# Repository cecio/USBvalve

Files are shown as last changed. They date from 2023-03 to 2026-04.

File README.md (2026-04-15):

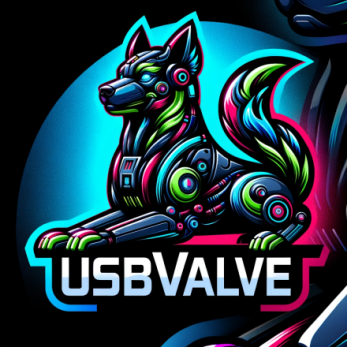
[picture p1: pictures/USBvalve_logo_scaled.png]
logo, landscape, dark text, transparent background
<h1></a></h1>

> [!NOTE]
> **USBvalve Version 1.0.0**
>
> A complete rewrite of the application has been done:
> - moved away from Arduino IDE environment, now the code is written for the [Pi Pico SDK](https://github.com/raspberrypi/pico-sdk)
> - dependencies on external libraries have been reduced a lot
> - USB host support for Low Speed devices is now more robust (ATTiny85, EvilCrow, etc)
> -  hardware and functionalities are almost unchanged, see the [notes](https://github.com/cecio/USBvalve#notes-about-bootsel-and-version--100) below for details 

### *Expose USB activity on the fly*

<p float="left">
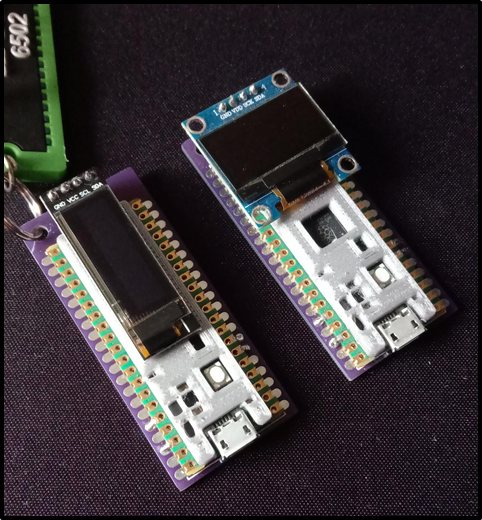
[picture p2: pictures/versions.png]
The two models

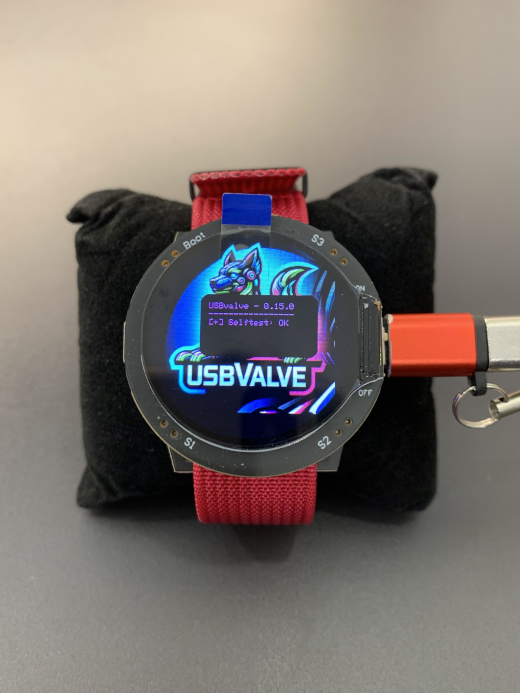
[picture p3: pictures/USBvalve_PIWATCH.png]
The Watch

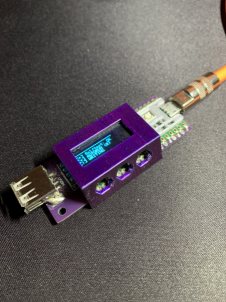
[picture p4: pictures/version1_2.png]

</p>

I'm sure that, like me, you were asked to put your USB drive in an *unknown* device...and then the doubt: 

what happened to my  poor dongle, behind the scene? Stealing my files? Encrypting them? Or  *just* installing a malware? With **USBvalve** you can spot this out in  seconds: built on super cheap off-the-shelf hardware you can quickly  test any USB file system activity and understand what is going on before it's too late!

With **USBvalve** you can have an immediate feedback about what happen to the drive; the screen will show you if the *fake* filesystem built on the device is accessed, read or written:

<p float="left">
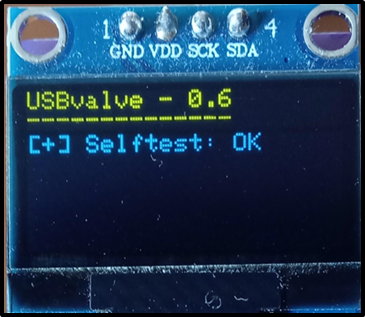
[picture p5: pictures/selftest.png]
Selftest

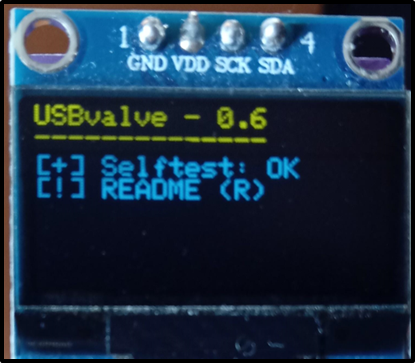
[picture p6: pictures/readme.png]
Readme

</p>

and from version `0.8.0` you can also use it as USB Host to detect *BADUSB* devices:

<p float="left">
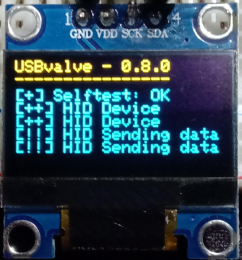
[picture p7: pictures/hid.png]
HID

</p>

This is an example of the *BADUSB* debugger available on serial port:

<p float="left">

</p>

If you prefer videos, you can also have a look to my [Insomni'hack Presentation](https://www.youtube.com/watch?v=jy1filtQY4w)

## USBvalve Watch

Starting from version `0.15.0` a new *Pi Pico Watch* version is supported. To compile the new version you have to uncomment the `#define PIWATCH` line at the beginning of the code. The hardware is a RP2040-based 1.28-inch TFT display and watch board. You can find some more info [here](https://www.raspberrypi.com/news/how-to-build-your-own-raspberry-pi-watch/).
This is also fully compatible with the [Waveshare RP2040-LCD-1.28](https://www.waveshare.com/wiki/RP2040-LCD-1.28).

## Repository Structure

`docs`: documentation about the project, with a presentation where you can have a look to all the features

`firmware`: pre-built firmwares for the Raspberry Pi Pico. You can just use these and flash them on the board. We have several different versions, for 32 or 64 lines OLEDs, for Pico 1 or Pico2, Pi Pico Watch, etc

`PCB`: Gerber file if you want to print the custom PCB . It's not mandatory, you can use your own or build it on a breadboard

`src` and `data`: sources, if you want to modify and build the firmware yourself

`utils`: some utilities you may use to build a custom FS

`pictures`: images and resources used in this doc

`STL`: STL files for enclosure. In `1.1` and `1.2` folders there are full enclosures (thanks to [WhistleMaster](https://github.com/WhistleMaster)). In folders `1.2_64` and `1.2_64_simple` there are enclosures for the 128x64 screen (thanks to [rtmq0227](https://github.com/rtmq0227)). If you want something lighter to protect the LCD you can go with `USBvalve_sliding_cover.stl`.

## Build USBvalve

### Part list

If you want to build your own, you need:

- A Raspberry Pi Pico 1 or 2 (or another RP2040 based board)
- an I2C OLED screen 128x64 or 128x32 (**SSD1306**)
- (optional) a **USBvalve** PCB or a breadboard
- (optional) a 3D printed spacer to isolate the screen from the board (https://www.thingiverse.com/thing:4748043), but you can use a piece of electrical tape instead

### Notes about BOOTSEL and version >= 1.0.0

In the `0.x.x` versions, BOOTSEL was used to reset the device or print the number of HID events (press > 2s).
The polling of BOOTSEL was creating some issues to the *BADUSB* detection so this was removed from version `1.0.0` and replaced with the following two options:
- solder a button between `GP0` and `GND` (pads 1 and 3, see pic below to see an example) to have the same functions
- use the commands `r` (reset) and `h` (HID events) from the serial monitor

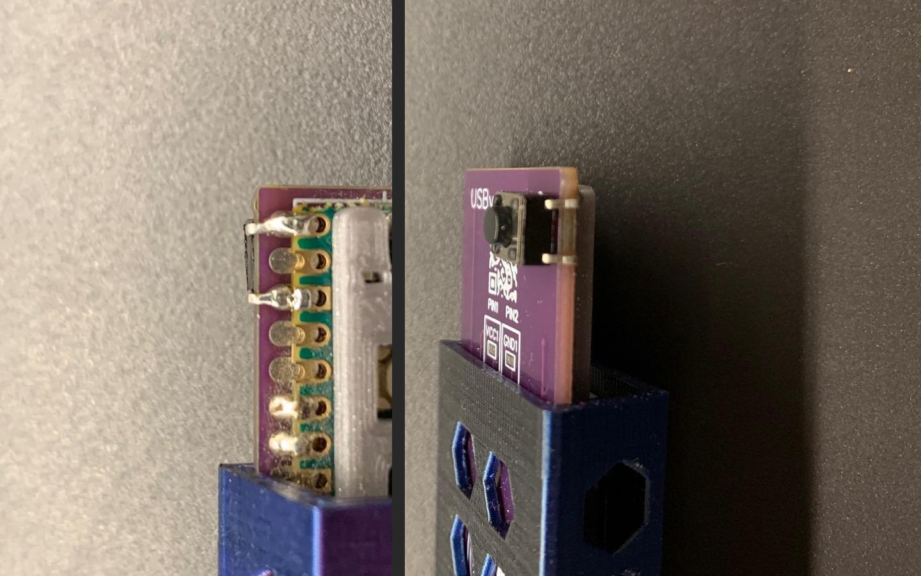
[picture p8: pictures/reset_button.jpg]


In `PCB` you'll find also a version `1.3` of the board, with some holes on pads 1 and 3 to facilitate the mount of the button. But as you can see, you can also use your old version.

If you are not using the *BADUSB* functions or if you prefer to have less coverage on detection but keep BOOTSEL usage, I'm also providing a firmware created with *bootsel* enabled (see folder and releases).

### Building instructions

> Thanks to [Tz1rf](https://github.com/Tz1rf) we also have two great videos: one explaining the [building](https://youtu.be/7ymk8hD7-Hc) process step-by-step, and another showing how to [upload firmware](https://youtu.be/Tp8xvrlqxUY) and use the tool.

Almost all the job is done directly on the board by the software, so you just need to arrange the connection with the OLED for output.

Starting from version 0.8.0 of the firmware, **USBvalve** can detect HID devices (used to detect *BADUSB*). This require an additional USB port behaving as Host. If you are not interested in this, you can use the old instructions [in docs folder](https://github.com/cecio/USBvalve/blob/main/docs/BUILDING-1.1.md) and use PCB version `1.1`. Otherwise go ahead with PCB version `1.2` (we have version for USB-A or USB-B, see folder).

#### With USBvalve PCB

<p float="left">
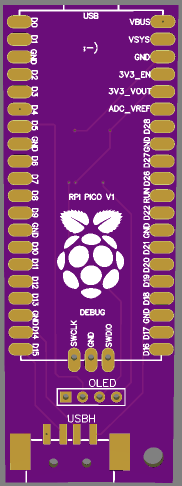
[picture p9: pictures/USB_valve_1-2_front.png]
  
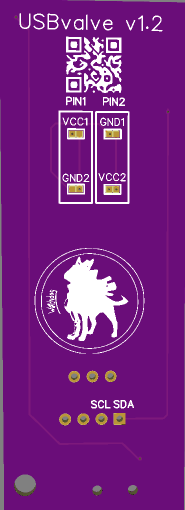
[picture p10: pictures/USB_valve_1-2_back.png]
   
</p>

- solder a USB female port in `USBH` area. This is for version `A`, but there is a version for USB `Micro-B` as well if you prefer
- place the Raspberry Pi Pico on the silk screen on the front 
- you don't need to solder all the PINs. Just the following:
  - D4 and D5 (left side)
  - D14 and D15 (left side)
  - GND (right side, third pin from the top)
  - GND (right side, third pin from the bottom)
  - 3v3_OUT (right side)
  - VBUS (right side)
  - the 3 DEBUG pin on the bottom: SWCLK, GND and SWDIO
- place the 3D printer spacer or a piece of tape on the parts of the OLED that my touch the Raspberry
- solder the OLED (with a header) on the 4 PIN space

Some of the OLEDs have the GND and VCC PINs swapped, so I built the PCB to be compatible with both versions: 

For example if your OLED has GND on PIN1 and VCC on PIN2 like this:

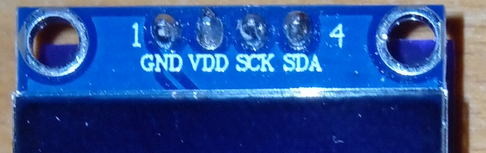
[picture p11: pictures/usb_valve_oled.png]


You have to place a blob of solder on these two pads on the back of the PCB:

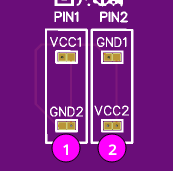
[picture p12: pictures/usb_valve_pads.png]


Otherwise you should the opposite and place the solder on the other PADs:

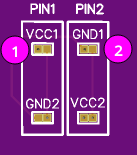
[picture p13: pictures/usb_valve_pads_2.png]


#### Without USBvalve PCB

Pico Pi

If you are using a breadboard or just wiring, all you have to do is to ensure to connect the proper PINs at the OLED screen and to the Host USB port.

The mapping is the following:

- PIN6 of Pi --> OLED SDA
- PIN7 of Pi --> OLED SCL 
- PIN19 of Pi --> D+ of USB Host
- PIN20 of Pi --> D- of USB Host
- PIN23 (GND) of Pi --> GND of USB Host
- PIN38 (GND) of Pi --> OLED GND
- PIN36 (3V3OUT) of Pi --> OLED VCC
- PIN40 (VBUS) of Pi --> VCC of USB Host

If you want to use the DEBUG functions, you can also place a header on the 3 SWD PINs at the bottom of the board.

#### With USBpipe PCB

> [!CAUTION]
> This PCB is for experienced electronic makers
> **DON'T USE IT IF YOU AREN'T SURE YOU CAN HANDLE IT!**

> [!NOTE]
> R7 and R8 aren't actually connected to anything. They are added for circuit debugging purposes.
> So they don't show up in the BOM

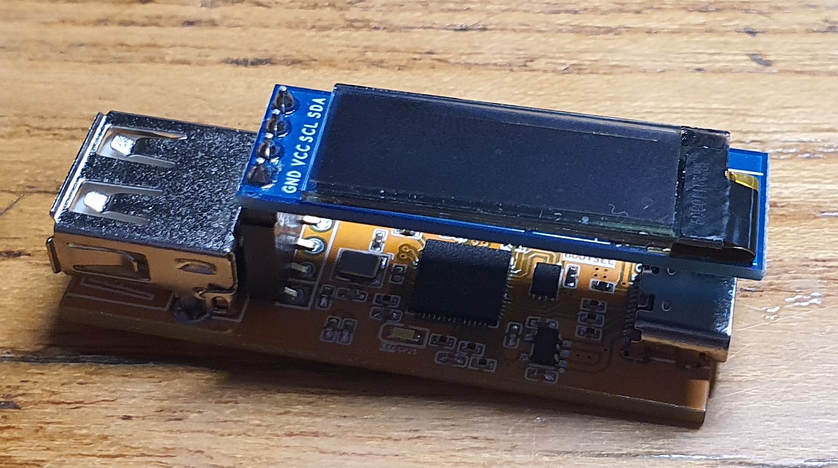
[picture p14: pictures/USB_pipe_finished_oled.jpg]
USBpipe PCB


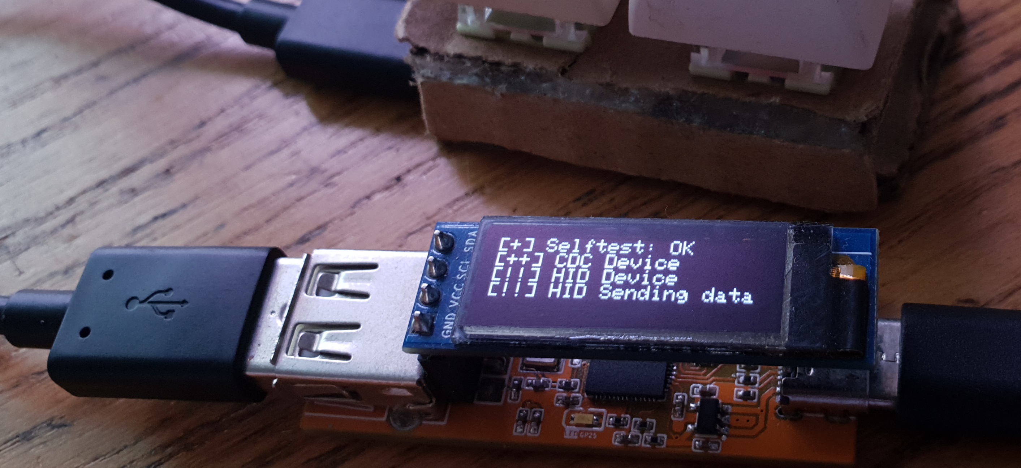
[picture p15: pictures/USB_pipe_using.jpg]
USBpipe


[USBpipe](https://github.com/LiPolymer/smartUSBPipe) is a dedicated PCB for this project.

You can find everything you need in `./PCB/USBpipe/` folder.

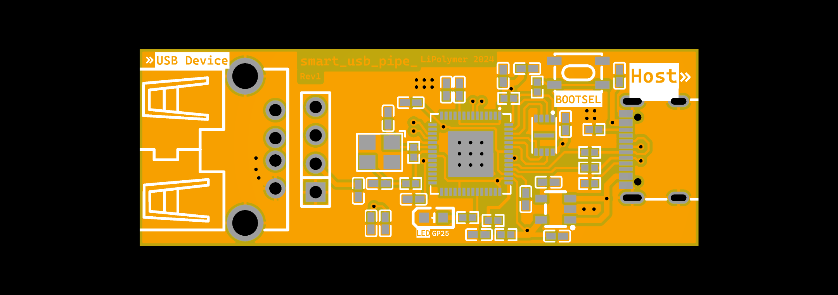
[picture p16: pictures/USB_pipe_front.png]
Front


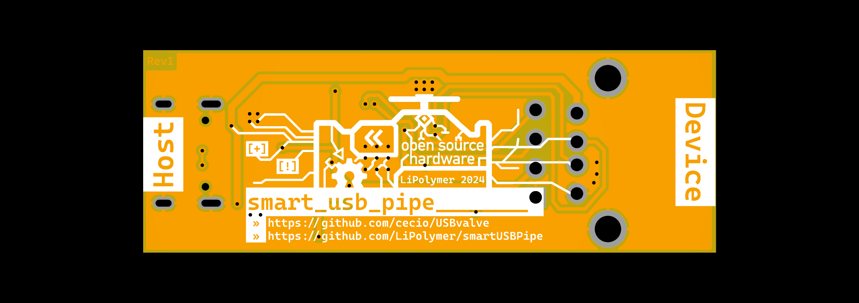
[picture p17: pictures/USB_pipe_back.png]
Back


### Flash Firmware

To flash the firmware, follow these steps:

- Connect the Raspberry Pi Pico with the USB cable, by keeping the *BOOTSEL* button pressed (the big white button on the board)
- release the button
- you will see a new drive on the system, named `RPI-RP2` (in Linux envs you may have to manually mount it)
- copy the proper firmware file (with extension `uf2`) in the folder, depending on the OLED you used
- wait few seconds until the mounted folder disappear

It's done!

### Anti-Detection

I don't know if it will ever be the case, but you may want to customize the firmware in order to avoid detection done by *USBvalve-aware* malware :-)

I grouped most of the variables you may want to modify in this section of `usb_config.h` ([see Dockerfile below for rebuilding](https://github.com/cecio/USBvalve#dockerfile))

```C
// USB anti-detection settings
//
// Set USB IDs strings and numbers, to avoid possible detections.
// Remember that you can cusotmize FAKE_DISK_BLOCK_NUM as well
// for the same reason. Also DISK_LABEL in ramdisk.h can be changed.
//
// You can see here for inspiration: https://the-sz.com/products/usbid/
//
// Example:
//             0x0951 0x16D5    VENDORID_STR: Kingston   PRODUCTID_STR: DataTraveler
//
#define USB_VENDORID       0x0951
#define USB_PRODUCTID      0x16D5
#define USB_DESCRIPTOR     "DataTraveler"
#define USB_MANUF          "Kingston"
#define USB_SERIAL         "123456789A"
#define USB_VENDORID_STR   "Kingston"        // Up to 8 chars
#define USB_PRODUCTID_STR  "DataTraveler"    // Up to 16 chars
#define USB_VERSION_STR    "1.0"             // Up to 4 chars
```

### Building your firmware

Obviously you can also build your own firmware. To build you need the *Raspberry Pi Pico SDK* and this repoository.

Basic recompile instructions:
```
export PICO_SDK_PATH=</path/to/pico-sdk>

git clone --recursive https://github.com/cecio/USBvalve.git
cd USBvalve
mkdir build && cd build
cmake -DPICO_BOARD=pico ..   # or pico2 for standard build
make -j$(nproc)
# Output: build/src/USBvalve.uf2
```

If you want to re-create a new fake filesystem, you may want to have a look to the `utils` folder, where I placed some utilities to build a new one.

#### Dockerfile

If you want to build your own firmware, after you customized it, I provide a `Dockerfile` which builds a complete building environment and compile the firmware. 

Enter the following commands in the main `USBvalve` folder to build:

```
# To Build:
#       docker build -t usbvalve-sdk -f Dockerfile.sdk .
#
# To Run (default: pico, SSD1306 OLED 128x32):
#       docker run --rm -v $PWD:/mnt usbvalve-sdk
#
# Options (via environment variables):
#       BOARD=pico|pico2          Board target (default: pico)
#       OLED_HEIGHT=32|64         OLED display height (default: 32)
#       PIWATCH=1                 Use GC9A01 round TFT instead of SSD1306
#       USE_BOOTSEL=1             Enable BOOTSEL button (disrupts Low Speed USB)
#
# Examples:
#       docker run --rm -e BOARD=pico2 -v $PWD:/mnt usbvalve-sdk
#       docker run --rm -e PIWATCH=1 -v $PWD:/mnt usbvalve-sdk
#       docker run --rm -e BOARD=pico2 -e OLED_HEIGHT=64 -v $PWD:/mnt usbvalve-sdk
```

The firmware will be placed with extension `uf2` in folder `USBvalve_out`.

### Contribute

If you have ideas or improvements in your mind, I encourage you to open an issue so that we can improve the project together! Thanks!

### Support

If you have question or need support you can open an `Issue` here or reach me out on Twitter/X [@red5heep](https://twitter.com/red5heep)

### Community versions

The Community created some forks implementing support for other boards, or other modifications. **Thank you to everyone** who contributed to the development of **USBvalve**.
Here below an unofficial/incomplete/unsupported list:
- [USBvalve-tbfa-Mod](https://github.com/TryBreakFixAgain/USBvalve-tbfa-Mod)

## SAFETY WARNING

> [!WARNING]
> I've received a lot of questions about **USBvalve** and *USB killer devices*. **USBvalve** is not built to test these devices, it has not any kind of insulation or protection, so if you have the suspect you are dealing with one of these devices, test it with something else, NOT with **USBvalve** or you may damage the device, yourself or objects near to you.

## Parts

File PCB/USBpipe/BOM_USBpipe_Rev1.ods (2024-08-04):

No. | Quantity | Manufacturer Part | Value | Designato | Footprint | Comment | Manufacturer
1 | 1 | HX TS3425PA 250gf |  | BOOTSEL1 | SW-SMD_4P-L4.2-W3.4-P2.15-LS5.2 | HX TS3425PA 250gf | hanxia(韩下)
2 | 2 |  | 15pF | C1,C2 | C0402 | 15pF
3 | 3 |  | 2.2uF | C3,C4,C5 | C0402 | 2.2uF
4 | 8 |  | 100nF | C6,C7,C8,C9,C10,C11,C12,C13 | C0402 | 100nF
5 | 1 |  | 10nF | C14 | C0402 | 10nF
6 | 2 |  | 1uF | C15,C17 | C0402 | 1uF
7 | 1 |  | 10uF | C16 | C0402 | 10uF
8 | 1 | PZ254V-11-04P |  | H1 | HDR-TH_4P-P2.54-V-M | PZ254V-11-04P | XFCN(兴飞)
9 | 1 | SZYY0603B |  | LED1 | LED0603-R-RD_BLUE | SZYY0603B | yongyu(永裕光电)
10 | 1 |  | 10K | R1 | R0402 | 10K
11 | 2 |  | 5.1K | R2,R3 | R0402 | 5.1K
12 | 2 |  | 27R | R4,R5 | R0402 | 27R
13 | 1 |  | 200R | R6 | R0402 | 200R
14 | 1 |  | 1K | R9 | R0402 | 1K
15 | 1 |  | 1R | R10 | R0402 | 1R
16 | 1 |  | 470R | R11 | R0402 | 470R
17 | 1 | RP2040 |  | U1 | QFN-56_L7.0-W7.0-P0.40-TL-EP4.0 | RP2040 | Raspberry Pi(树莓派)
18 | 1 | W25Q16JVUXIQ |  | U2 | USON-8_L3.0-W2.0-P0.50-BL-EP | W25Q16JVUXIQ | WINBOND(华邦)
19 | 1 | Type-C-TOP_1 |  | U3 | USB-C-SMD_TYPE-C16PIN | Type-C-TOP_1
20 | 1 | SGM2028-3.3 |  | U4 | SOT-23-5_L3.0-W1.7-P0.95-LS2.8-BR | SGM2028-3.3 | SGMICRO(圣邦微)
21 | 1 | AF 90° WJDG |  | USB1 | USB-A-TH_AF-WJDG | AF 90° WJDG | SHOU HAN(首韩)
22 | 1 | X322512MSB4SI | 12MHz | X1 | OSC-SMD_4P-L3.2-W2.5-BL | 12MHz | YXC(扬兴晶振)
 | NOTE: R7 and R8 aren't actually connected to anything. They are added for circuit debugging purposes.
 | 注意: R7和R8为测试用焊盘,并不连接到任何元件

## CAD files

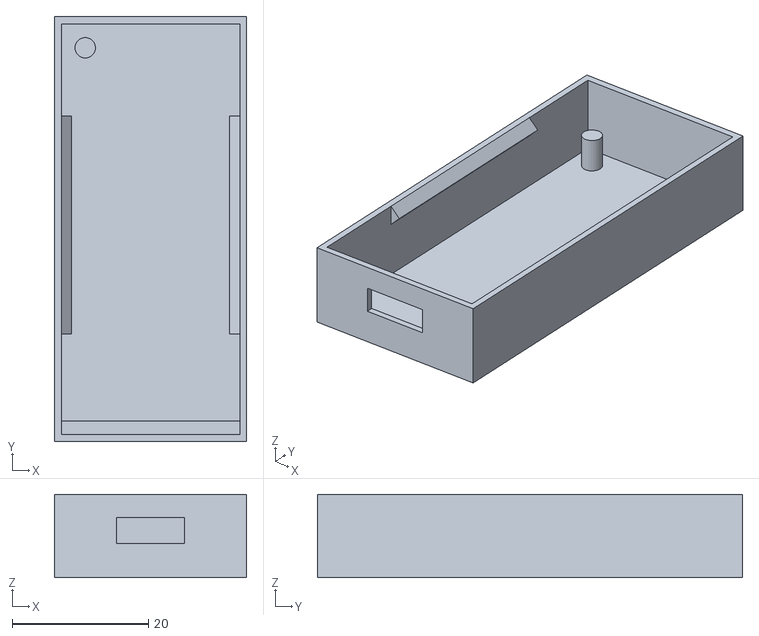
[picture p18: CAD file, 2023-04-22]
STL/1.1/Box_USBvalve_1.1.stl
28.2 x 62.4 x 12.2

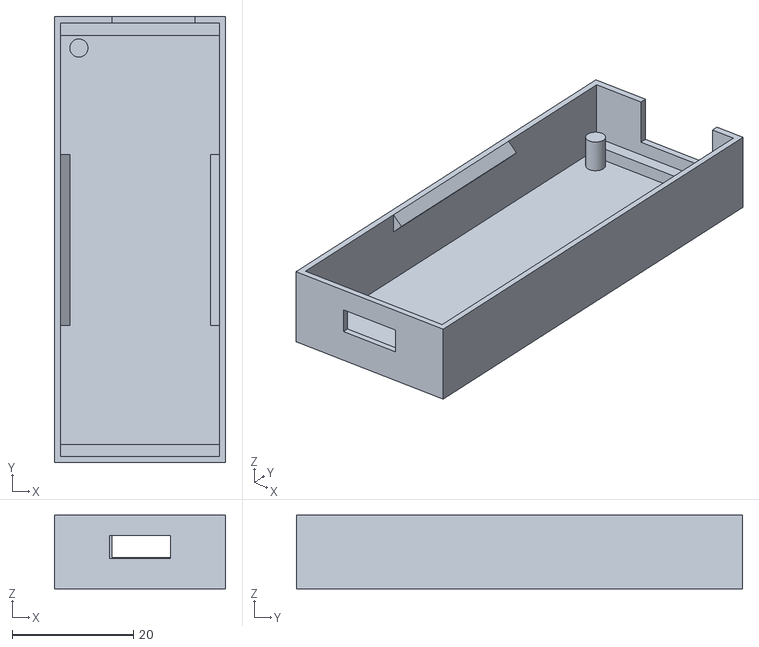
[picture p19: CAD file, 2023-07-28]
STL/1.2/Box_USBvalve_1.2.stl
28.2 x 73.5 x 12.2

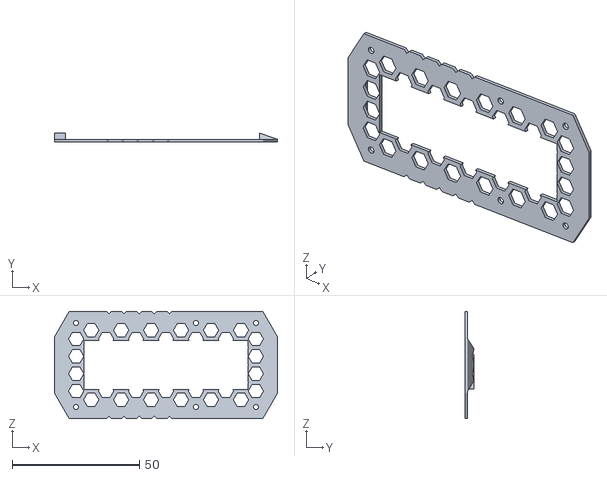
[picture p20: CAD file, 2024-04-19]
STL/1.2_64/renclosure_spacer.stl
87.5 x 3.50 x 42.1

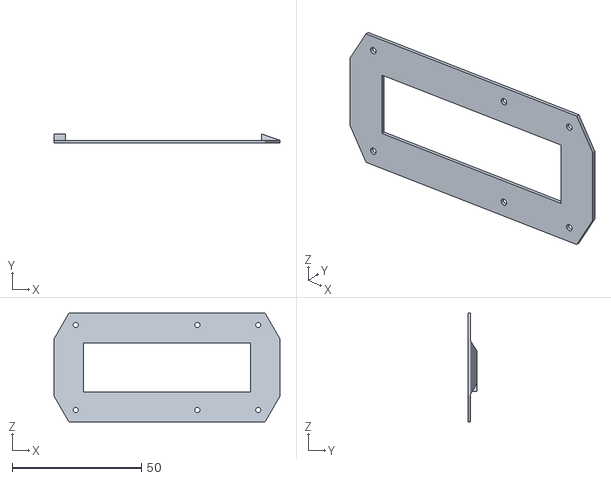
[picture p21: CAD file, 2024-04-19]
STL/1.2_64_simple/SimpleEnclosurex64_spacer.stl
87.5 x 3.50 x 42.1

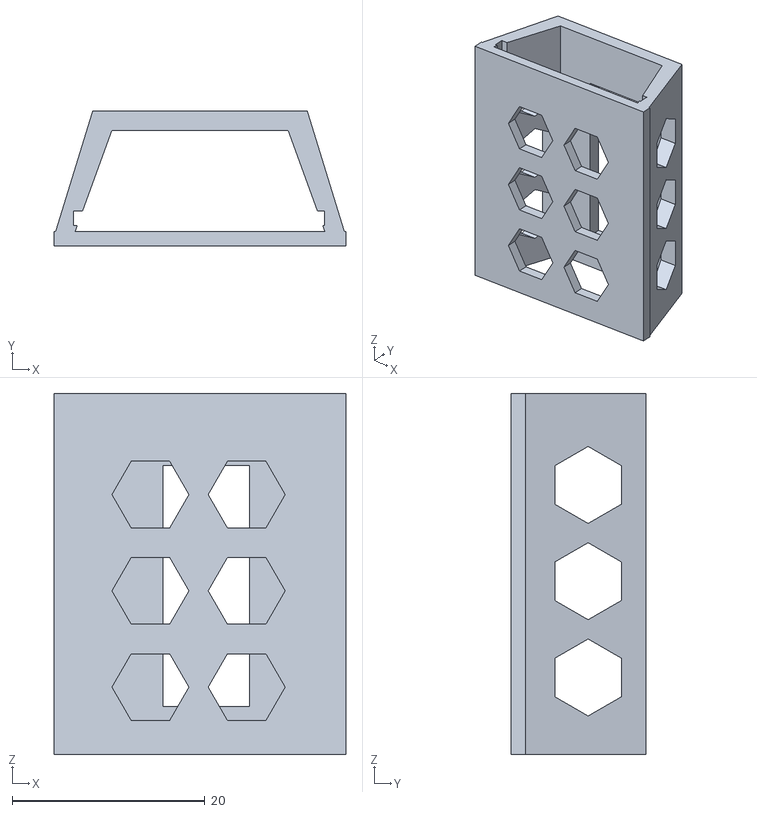
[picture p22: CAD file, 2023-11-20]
STL/USBvalve_sliding_cover.stl
30.3 x 14.0 x 37.5

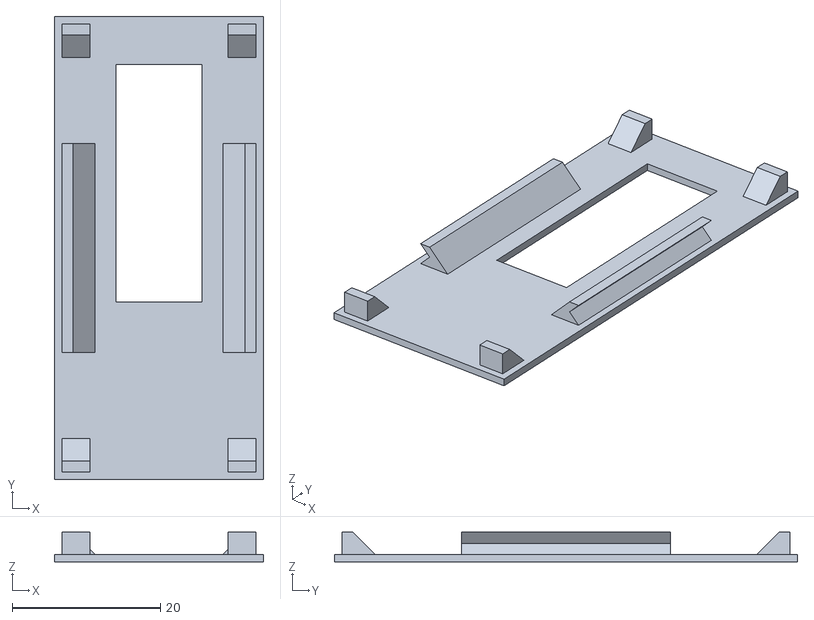
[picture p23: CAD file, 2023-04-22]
STL/1.1/Cover_32_USBvalve_1.1.stl
28.2 x 62.4 x 4.00

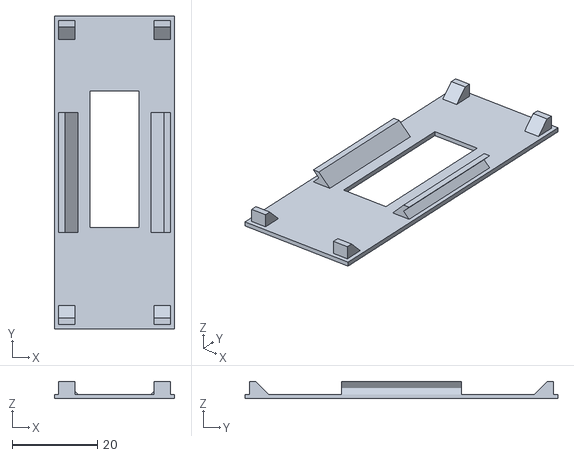
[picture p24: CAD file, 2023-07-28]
STL/1.2/Cover_32_USBvalve_1.2.stl
28.2 x 73.5 x 4.00

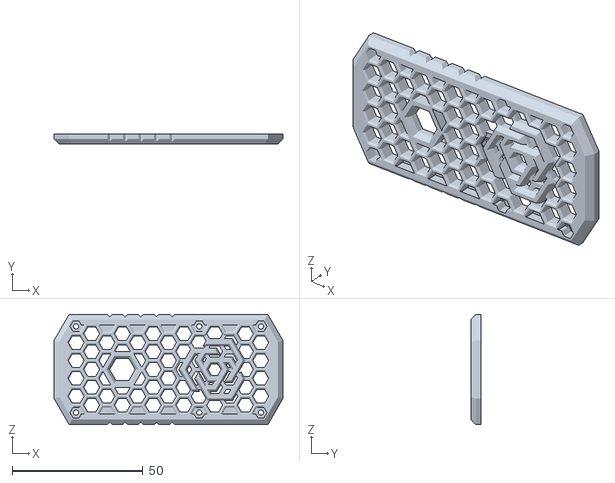
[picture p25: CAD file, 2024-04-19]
STL/1.2_64/renclosure_backplate.stl
87.5 x 4.00 x 42.1

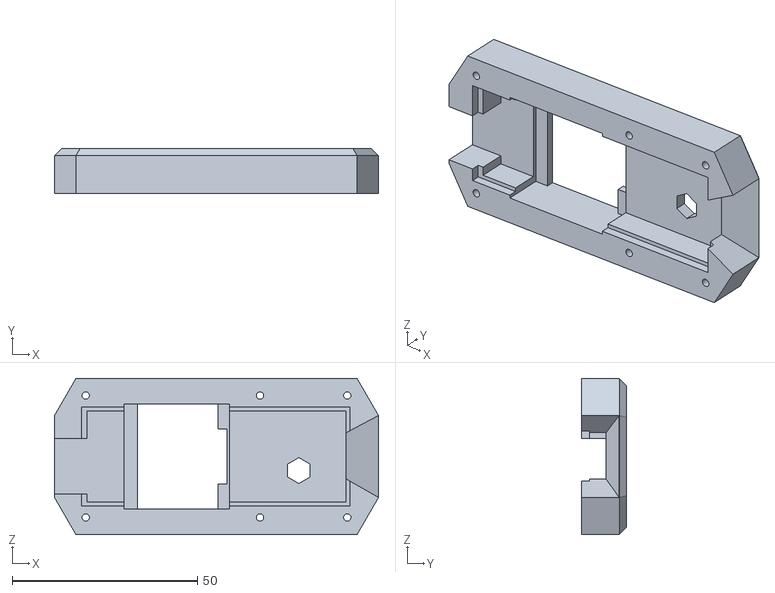
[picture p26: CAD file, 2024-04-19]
STL/1.2_64_simple/SimpleEnclosurex64.stl
87.5 x 12.2 x 42.1

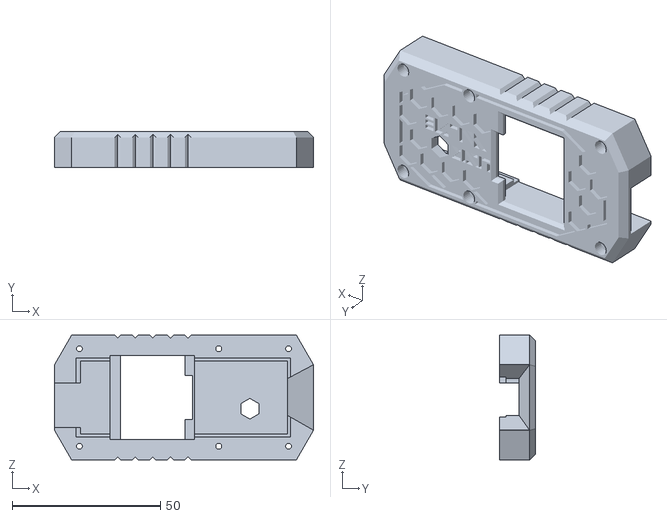
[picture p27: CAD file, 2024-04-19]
STL/1.2_64/renclosure.stl
87.5 x 12.2 x 42.1

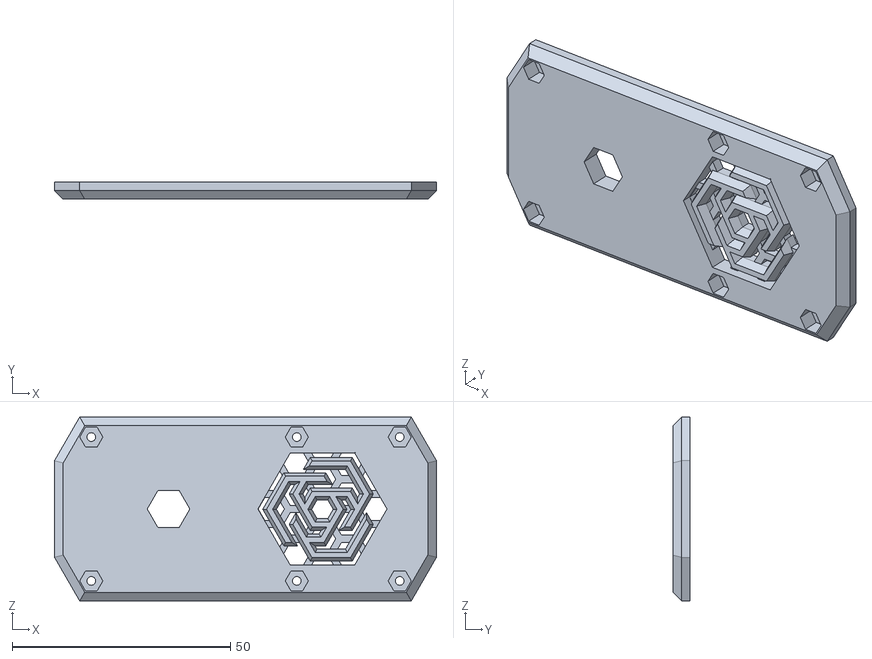
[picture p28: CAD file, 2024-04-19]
STL/1.2_64_simple/SimpleEnclosurex64_backplate.stl
87.5 x 4.00 x 42.1

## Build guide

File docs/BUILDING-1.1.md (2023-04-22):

#### With USBvalve PCB

<p float="left">
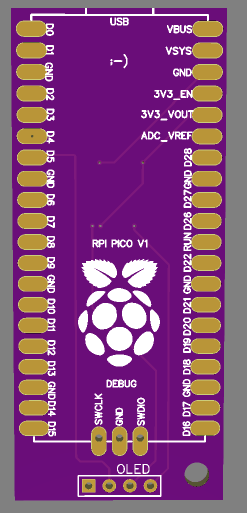
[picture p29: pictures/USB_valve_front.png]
  
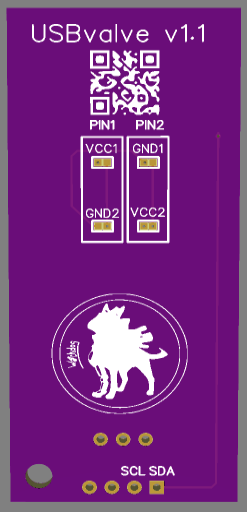
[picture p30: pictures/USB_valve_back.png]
   
</p>

- place the Raspberry Pi Pico on the silk screen on the front 
- you don't need to solder all the PINs. Just the following:
  - D4 and D5 (left side)
  - GND (right side)
  - 3v3_OUT (right side)
  - the 3 DEBUG pin on the bottom: SWCLK, GND and SWDIO
- place the 3D printer spacer or a piece of tape on the parts of the OLED that my touch the Raspberry
- solder the OLED (with a header) on the 4 PIN space

Some of the OLEDs have the GND and VCC PINs swapped, so I built the PCB to be compatible with both versions: 

For example if your OLED has GND on PIN1 and VCC on PIN2 like this:



You have to place a blob of solder on these two pads on the back of the PCB:



Otherwise you should the opposite and place the solder on the other PADs:



#### Without USBvalve PCB

Pico Pi

If you are using a breadboard or just wiring, all you have to do is to ensure to connect the proper PINs at the OLED screen.

The mapping is the following:

- PIN6 of Pi --> OLED SDA
- PIN7 of Pi --> OLED SCL 
- PIN38 (GND) of Pi --> OLED GND
- PIN36 (3V3OUT) of Pi --> OLED VCC

If you want to use the DEBUG functions, you can also place a header on the 3 SWD PINs at the bottom of the board.

### Flash Firmware

To flash the firmware, follow these steps:

- Connect the Raspberry Pi Pico with the USB cable, by keeping the *BOOTSEL* button pressed (the big white button on the board)
- release the button
- you will see a new drive on the system, named `RPI-RP2` (in Linux envs you may have to manually mount it)
- copy the proper firmware file (with extension `uf2`) in the folder, depending on the OLED you used
- wait few seconds until the mounted folder disappear

It's done!

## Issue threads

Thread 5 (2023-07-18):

KillerUSB

cecio, 2023-07-18:
Chances are that it will be destroyed, so we can think it as a **sacrificial device** ;-)
...it costs a few bucks :-)

Better this than your main PC!

**Need to be tested!**

csdragon83, 2023-08-28:
I also guess that it will be fried...

For USB-Kill I recommend:
https://usbkill.com/collections/usbkill-accessories/products/usbkill-shield
(even when the old one was cooler... you were able to do sparks with it)

cecio, 2023-08-28:
ah, I didn't know it existed! Nice!

Zorakie, 2024-03-22:
Hi, this my question is somewhat related.

If I add the USB-A for passthrough testing, and for some reason, that device will also sends power (like battery operated device, or something that is also plugged to the wall, say, USB-hub that also has power passthrough and is connected to laptop charger), is there any on-board protection for this power coming from the other side, or it will just fry the device?

Thanks! :)

cecio, 2024-03-22:
Usually host devices (even if battery operated) do not send power over the USB connection, they get power from it.
During my tests I used a lot of them and I never found one sending power over that line.
This does not exclude that a malfunctioning one (or a malicious one) can do it.

Looking at the Raspberry Pi Docs, I understand that the VBUS pin (the one attached to the power of the USB Host port) does not have a diode, so power coming in MAY damage the device (probably this depends on a lot of factors). A possible solution could be to attach the line to the VSYS pin, which actually have a diode. But in this case you may open an opposite issue: VBUS gets power from the USB Pico port, so it will be for sure at 5v and it will not damage your host. VSYS deliver the external power voltage (if you are powering the Pico externally) and that could damage your USB Host device (but only if you are powering it externally).

Side note: I see that you are referring to the USB-A as "passthrough" port, but it is not really that: the two USB ports are independent.

cecio, 2024-03-22:
Giving a deeper look at the Pico schematics, may be that even VSYS is not a solution in this case: if I'm not wrong the diode protects from backfeeding into the USB power source.
The real solution here is to apply an external diode probably.

frankrpeters, 2024-05-14:
As I also mentioned in the ATTiny/USBKill issue, a few TVS diodes and a polyfuse might protect the device and connected PC from damage.

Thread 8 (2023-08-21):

2 devices not recognized

csdragon83, 2023-08-21:
Hi!

First of all: you did a great job creating this little device...
I meanwhile made 3 if them...

But 2 hacking devices from me were not recognized...

1.:
"Duckhunter" is not recognized...

Duckhunter is a app within Nethunter that interprets Duckyscripts.
Nethunter is a Kali Linux arsenal that can be installed to Android devices..

In Nethunter there is the function "USB arsenal". With it you can enable the function "HID".
When I now start an attack at a computer the app "Duckhunter" interprets the Duckyscripts and types them in via the connected USB cable.
For that the android setting "USB Debugging" needs to be activated on the Android device.

Now I thought that the USB valve would also recognize the key strokes...
But it completely doesn't...
It doesn't recognize when I change my phone to HID mode and it doesn't recognize the key strokes...

2.:
The second device is a little "CJMCU" - a little Mini Atmega32U4 development board for about 7€ that also can do keystrokes...
At the moment I have set it to type in 0000 to 9999 but the USB valve also doesn't recognize the keystrokes of this little device...

Maybe you could add a function so that this devices also  can be recognized...

Best regards
Csdragon

cecio, 2023-08-21:
Thanks for the kind words, and for opening the issue.

A couple of questions:

- are the devices not recognized at all, or just the keystrokes? I mean, when you plug the device, do you see an `HID Device` message on the OLED screen, or nothing at all?
- for the NetHunter app, did you tried to switch before to HID and then (after that) plug the device into USBvalve?
- the CJMCU device is also named "CJMCU-Beetle"? I can try to buy one to do a couple of tests

Thanks,

cecio, 2023-08-21:
Ok, I think I found something, not sure if this is the same issue you are experiencing, but may be:

it looks like the overclocking of the CPU is in some way decreasing the compatibility with some HID devices, not sure why. May I send you a debug version of the firmware with a 120Mhz firmware (let me know if 32 o 64 lines screen) and may be you can do some testing with your devices?

Thanks,

csdragon83, 2023-08-22:
> it looks like the overclocking of the CPU is in some way decreasing the compatibility with some HID devices, not sure why. May I send you a debug version of the firmware with a 120Mhz firmware (let me know if 32 o 64 lines screen) and may be you can do some testing with your devices?

Would be no problem!
I've got a 32 lines display.

csdragon83, 2023-08-22:
To the CJMCU device: I hope I can manage to have a look at it this evening.

cecio, 2023-08-22:
No worries at all, take your time. And thanks for your help!

In the meantime, here is the link for a new test version (0.13.0): https://icedrive.net/s/8SbF9bD7N27k1vGYBtDVya9FCjzk

Let me know how it works with the two devices.

Thanks again.

csdragon83, 2023-08-28:
Hi!

Installed it to my USB-Valve...
Well... most of the time it is recognized now... but about one time in 20-30 times restarting it an then plugging it in it is not recognized...

I can plug it in, unplug it a lot of time - nothing on the display...
Reboot by button of the USB-Valve and it is recognized...

To the CJMCU device: sorry have a big construction site at home at the moment... was not able to have a look yet...

csdragon83, 2023-08-30:
The Hardware I use is a Digispark hw-018
Costs about 2,50€ at ebay.

cecio, 2023-09-02:
I ordered one, should receive it next week. I'm curious to check it out.

Thanks,

cecio, 2023-09-05:
I received the device and to be honest I'm a bit puzzled:

the device itself has something wrong: I tested it in two different laptops (a Dell with Linux and a Lenovo with Windows) and none of them recognize it. Even if it receives power (and the led turns on), the device is not recognized if inserted in the built-in USB ports of both the systems.
I think the PCB is too thin and it does not fit correctly in the USB ports. If I compare it with `Adafruit Neokey` (https://www.adafruit.com/product/5020), it is almost 0.5mm less, which is a lot.
`Adafruit Neokey` works perfectly with all my laptops and USBvalve as well.

I had to use a specific USB extension (but a couple I had were not working as well) and with this I have the Digispark device recognized 50% of the time by the laptops and by USBvalve as well. But it is not reliable in any case.

May be I received a defective device (but the PCB thickness is an issue in any case)...otherwise I don't think this is a USBvalve issue. It looks like a connection issue.

cecio, 2023-09-05:
May I ask you a favor?

I have a new version of the firmware: https://icedrive.net/s/NT52Z44k2k4PbD2YxvbtYSyiNyVY

Could you please test it with NetHunter? I'd like to check if this new version keeps the compatibility.
You can also check it with the Digispark device, even if I don't expect it works with that.

Thanks a lot!

twhp-electronic, 2023-10-18:
Sorry... Just saw today, that you updated to a new version.
Works very well with NetHunter.
As soon as I change USB to HID it is recognized.

cecio, 2023-10-18:
oh no worries at all... :-)
Thanks for the checks!!

Regarding the Digispark, please try, but I'm pretty sure it will not work. The reason why this is not recognized is still puzzling me...or may be I have a defective device.

Thanks a lot!

csdragon83, 2025-05-02:
I found a new device that is not recognized...

https://github.com/joelsernamoreno/EvilCrow-Cable

cecio, 2025-05-02:
Thanks for letting me know. I ordered one, as soon as I'll get it, I'll have a look.

csdragon83, 2025-05-06:
If you need example code: please let me know!

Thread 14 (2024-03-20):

pcb board ordering suggestions

tbyoda, 2024-03-20:
hello great project and seen this on LTT and want  to build this great project. However i have never ordered hobbyists pcbs. whom are you using for this project? i wouldn’t mind ordering a few boards if others want to go in or if you have some boards left over buy from you. please let me know. i have ordered pico and screen.

ondrejhonus, 2024-03-20:
Hey man, I just ordered 5 pcbs yesterday for total of 3$ incl. shipping from [jlcpcb.com](https://jlcpcb.com/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). You just download the PCB zip from this github dir and you upload the zip to the jlcpcb website. That’s basically all, it’s easy.

tbyoda, 2024-03-20:
Thank you very much , I thought it would be easy but wasn’t totally sure. I
can’t wait to make this project will be fun learning process.
Robert

On Wed, Mar 20, 2024 at 1:21 AM Ondřej Honus ***@***.***>
wrote:

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

timothy-fyi, 2024-03-26:
> Hey man, I just ordered 5 pcbs yesterday for total of 3$ incl. shipping from [jlcpcb.com](https://jlcpcb.com/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). You just download the PCB zip from this github dir and you upload the zip to the jlcpcb website. That’s basically all, it’s easy.

you didn't need to get it assembled/attach a BOM? that's my current problem. I know how up upload the Gerber files to jlcpcb, but I wasn't sure if I needed it assembled as well

tbyoda, 2024-03-26:
No i don’t need any assembly. I am a RF Engineer by trade so this will be
easy.

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

Sin-Thor, 2024-04-18:
> No i don’t need any assembly. I am a RF Engineer by trade so this will be easy.
> […](#)
> On Tue, Mar 26, 2024 at 5:44 PM Tim ***@***.***> wrote: Hey man, I just ordered 5 pcbs yesterday for total of 3$ incl. shipping from jlcpcb.com <https://jlcpcb.com/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>. You just download the PCB zip from this github dir and you upload the zip to the jlcpcb website. That’s basically all, it’s easy. you didn't need to get it assembled/attach a BOM? that's my current problem. I know how up upload the Gerber files to jlcpcb, but I wasn't sure if I needed it assembled as well — Reply to this email directly, view it on GitHub <[#14 (comment)](https://github.com/cecio/USBvalve/issues/14#issuecomment-2021525905)>, or unsubscribe <https://github.com/notifications/unsubscribe-auth/BHEDNMXKHEKF37RVYIHVSKDY2HT3ZAVCNFSM6AAAAABE6UUXMOVHI2DSMVQWIX3LMV43OSLTON2WKQ3PNVWWK3TUHMZDAMRRGUZDKOJQGU> . You are receiving this because you authored the thread.Message ID: ***@***.***>

I've never done anything like this before or ordered a pcb before, so not even sure if the pads to solder too are built into the board or not. If I want this usb pcb to be ready to go, out of the box, ready to be assembled with the raspberry, screen,  and usb port, which Delivery Option do I select between 'Single PCB', 'Panel by Customer' and 'Panel by JLCPCB' ?

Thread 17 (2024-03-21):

Possible with a USB-C version?

nmcbride, 2024-03-21:
I would like to build one of these but with USB-C on both sides.

I was thinking a Pro Pico and a USB-C on the other side.

Would this be possible?

cecio, 2024-03-21:
Hey, thanks for reaching out.

I had a look around for Pico USB-C versions: there are some of them and I noticed that they have a slightly different form factor (especially for the debug PINs), so probably you can not use any of the PCB nor the spacer for the OLED screen.

But if you are going to build your own version with a breadboard, it should work without problem. Remember that USB-C (for the host port) requires a resistor, so you should add it.
Actually I tested it some months ago (with a USB-C breakout), as you can see from the picture here: https://twitter.com/red5heep/status/1640812839525928986

I thought to create a PCB design with USB-C as Host port, but there is something that makes me doubtful about it: since the connection requires a resistor, I should do it with a SMD component and this is going to make the build of the board more difficult for beginners, so I never did it. But I might change my mind about this.

Zorakie, 2024-03-21:
Hi, I have just got my parts delivered and I genuinely thought it has USB-C as the main port (really, who uses micro these days on smart devices, where this matters). That being said, have you please tested, if I buy a simple Micro USB (male) to USB-C (female) reduction, and I plug it to PC, shopping mall charger, whatever, that it will work as expected? Thanks!

cecio, 2024-03-21:
hey, @Zorakie. I don't know why but the official Raspberry Pi Pico is still delivered with micro USB.
And, yes, with a converter it will work as expected!

kub3let, 2024-03-22:
There are third party boards like this https://de.aliexpress.com/item/1005006055009344.html with USB C.

Personally I would prefer to have a PCB version that has both USB A like it is now and USB C on the back so you can use either.

I Just ordered PCB's and will test if it works with the Tenstar Board.

cecio, 2024-03-22:
Thanks, let me know how it goes: the Tenstar Board seems to have a slightly different form factor.

I saw that some other "unofficial" releases have the same form factor with USB-C, like
https://www.aliexpress.us/item/3256805935885677.html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

kub3let, 2024-04-03:
PCB's arrived today, but the USB port is not working, after double checking and checking with a multimeter I noticed there isn't any ground trace for the USB port on the PCB ??

I will hotwire the ground, but it should be added to the gerber files.

Since this pico board comes with a RGB LED you don't even need the display technically or you can use them both, in that case the led works as background light for the display which is pretty cool.

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

entertheFinn, 2024-04-03:
This is what I am currently using as my USB C option. Unfortunately still working on getting the background to work like it does on the 1.28 inch screen. This is the o.99 inch B edition of the Waveshare RP2040. It accomplishes my USB C needs and is thinner than a lighter so you know I'll have multiple of these all over the place. That suitcase gets one. That toiletry bag. EDC gear. I have not tested inspecting traffic/payloads tho.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

nmcbride, 2024-04-03:
I was thinking of the pro pico as that is usb-c by default but I like the dual option with both the usb-c and usb-a.

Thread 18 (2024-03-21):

3D print enclosure?

Zorakie, 2024-03-21:
Hi! Any chance anyone has any blueprints for some enclosure? I have bought Pi Pico and 128*32 display and now I was thinking about how to put it together. I have ordered also some small plastic enclosure (Zonepi case, but it seems local) that fits more or less exactly the Pi itself.

Now, because the Pi has MicroUSB input, and in the reality, you will be testing rather USB-Cs (e.g. plug it to a mall phone charger, etc.), you will need a reduction. Then, there is this thing with adding the USB-A for passthrough testing, and then there is this thing with the OLED display.

I was already thinking around, how to put it together and it seems like it will be quite janky.

What I am looking for:
Enclosure that will fit the Pi itself and fully cover/protect it, will have hole for micro, will have hole for USB-A, will have proper place for display, that should be aligned with the box surface, and it should have some clips/compartment that will hold micro(m)->C(f) and A(m)->C(f) if you will need to switch between interfaces on-the-go. Of course, this enclosure must have enough space to put all the wiring inside, so it is actually a compact box over all.

Unfortunately, I do not have 3D printer, nor any experience with 3D modelling ...

So, anyone any ideas?

cecio, 2024-03-21:
Unfortunately I have very limited modelling capabilities as well, so the only thing I can do here is to forward the request to the community: if anyone want to contribute with something like this, it will be more than welcome :-)

Zorakie, 2024-03-21:
That's why I am asking here, but if you would be willing to ask, on twitter, or other social media of yours, and then include the blueprints to this repo somehow, considering somebody will make anything, that would be totally amazing! Thank you!

gamecioep, 2024-04-10:
I recently put a USBvalve together myself and am currently creating/printing an enclosure of it.
I can share this if you want (once I know that it fits correctly), but don't expect to much of it.
It is a very simple design (nothing too fancy) nor do I think that my design will fully accommodate every feature you want of it (specifically being able to place the cables inside.).
My current desing assumes that you used the PCB version.

SinStalker, 2024-04-19:
I found this that I plan to print once I put everything together and make sure it works. Maybe this will work for you.
[](https://www.thingiverse.com/thing:6557010/comments
)

cecio, 2024-04-19:
See Issue #36 a very nice enclosure has been added.

Closed 2024-04-20.

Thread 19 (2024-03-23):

RP2040 GEEKs Development Board

KonTy, 2024-03-23:
@cecio do you think RP2040 GEEKs Development Board can be modded to work with your firmware, as oppose to building a custom board? It seems that it would be much less painful if we could just mod this board and make it work?

https://www.ebay.com/itm/315215910989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

cecio, 2024-03-23:
Hey @KonTy , thanks for you interest in the project!

If you are interested in the USB mass device functionalities, the only issue to solve here is the LCD compatibility: I expect it will not work out of the box, but we should find a compatible library to use for that LCD (may be the one used for the PI Pico Watch is ok, but I expect that the PINs used will differ).

If you want to have also the USB HID detector, it's a bit more difficult: remapping the PIN used for D+ and D- is trivial, but I don't see any external PIN for VBUS or VSYS (which should be 5v). The only power PIN I see is 3.3v. For sure the PIN is somewhere on the board, but you should bring it out in some ways, so it would be a bit cumbersome to do.

KonTy, 2024-03-23:
@cecio I just bough that board, I will start looking into porting the fw to it. I think you are right I will try to get basic functionality first and then we could discuss USB HID functionality. TBH I think itwould give the community a huge boost if we could build this on top of a packaged solution like the one above so you won't have to build, solder things.

cecio, 2024-03-23:
Keep me posted on that! Thanks

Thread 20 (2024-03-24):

[Enhancement] device detected message

Zorakie, 2024-03-24:
When I first plugged my USBValve in, I thought my USB-A didn't work (bad solder, switched pins - as I was soldering it upside-down) or busted board because of my soldering ...

Well, if I put in for example a keyboard, it correctly starts detecting HID, but if I plug in a simple USB drive, there is nothing that would indicate that the device is actually plugged in, detected, or the board just knows about it in any other form (even if it would be just a detection that it consumes power on PIN 40.

It would be nice that if whenever a device is plugged in, there would be some info message first, before any error (if any) states would pop up.

cecio, 2024-03-24:
I'll look into that. Thanks!

cecio, 2024-03-25:
I added an initial support for this with release `0.16.0`.

Zorakie, 2024-03-25:
Works like charm. Thanks a lot!!

cecio, 2024-03-25:
Thanks to you for the suggestion!

Closed 2024-03-25.

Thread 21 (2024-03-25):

Ampel anzeige Ws2812b LED

TryBreakFixAgain, 2024-03-25:
Would it be possible to integrate a single Neopixel or Ws2812b control to make it easier to read for older or less tech. people?

I am thinking of:
Off = nothing connected
Blue = Something connected
Green = everything ok
Yellow = Attention
Red = something bad found

cecio, 2024-03-25:
Hey, thanks for your input.

Your idea is for sure interesting, and not to difficult to implement from a SW point of view. May be for HW is a bit more difficult: adding a Neopixel is going to complicate the DIY build.
I'm wondering to keep your idea for the pre-built board.
Anyway, thanks again for the idea. I'll try to integrate this somehow.

TryBreakFixAgain, 2024-03-25:
the hardware side should be less of a problem, 5v, gnd and one gpio. Single LED are now quite easy and cheap to get, I've tinkered with them a bit, but the system freezes when I try to control the led, but I'm a complete beginner when it comes to programming and not skilled enough to debug it

Great project

TryBreakFixAgain, 2024-03-28:
I tinkered a bit and found a quick and dirty solution based on NeoPixelConnect.

[https://github.com/MrYsLab/NeoPixelConnect](url)

My code is totally experimental and not professional, I don't know if it affects other functions. according to my tests everything seems to work so far.
I would be pleased if you could check whether my code affects the function. Or you might even see a possibility to include an improved version of my code in your project.  I would provide a modified PCB and a case design if my code does not affect the functions.

I have used a single WS2812B.
PIN36 (3V3) of Pi -> VCC
PIN38 (GND) of Pi -> GND
PIN14 of Pi -> Din
Yes I have only tapped the 3V3 instead of the 5V but it is enough to power the LED.

In order not to contaminate the whole code, I only modified the printout(), which is not so nice, but quick and dirty.

**Initialization**

    //START TryBreakFixAgain TrafficLight initialization
    #include <NeoPixelConnect.h>
    #define PixelPin        10 // PixelData Pin
    #define PixelNum 1 // Pixel count
    NeoPixelConnect pixels(PixelPin, PixelNum, pio0, 1);
    //END TryBreakFixAgain TrafficLight initialization

**modified printout()**

    void printout(const char *str)
    {
      display.print(str);
      // START TryBreakFixAgain TrafficLight
      String tlString = String(str);
      tlString.replace(String(char(10)), "");
      tlString.trim();
      if (tlString.substring(0,3) == "[+] ") {
        pixels.neoPixelFill(255, 255, 0, true);
      }
      else if (tlString.substring(0,3) == "[++") {
        pixels.neoPixelFill(0, 255, 0, true);
      }
      else if (tlString.substring(0,3) == "[!]") {
        pixels.neoPixelFill(255, 153, 51, true);
      }
      else if (tlString.substring(0,3) == "[!!") {
        pixels.neoPixelFill(255, 0, 0, true);
      }
      else {
        pixels.neoPixelFill(0, 0, 0, true);
        pixels.neoPixelClear(true);
      }
      // END TryBreakFixAgain TrafficLight
    }

cecio, 2024-03-28:
Thanks for your proposal.

I think your code is good, but it can be simpler in our case. It should work fine (I didn't tried it), but instead of using strings function to check the printout buffer it should be enough to check the booleans used to report anomalies:

```
boolean readme = false;
boolean autorun = false;
boolean written = false;
boolean deleted = false;
boolean written_reported = false;
boolean deleted_reported = false;
boolean hid_sent = false;
boolean hid_reported = false;
```
Also, the logic you are using is a bit strange: you are setting yellow for `[+]` messages, but that mean that yellow will be always set, since the `selftest` is printed with `[+]`. I would review it a bit.

I'm not sure I'm going to add this to the main branch, since I'd like to keep the HW build as simple as possible (and as I said I'll add something with the on-board led), but if you are going to work on it and create PCB and other things, I can create a dedicated branch for it, if you wish.

TryBreakFixAgain, 2024-03-29:
thank you very much, i am new to coding, i belong more to the 3d printing and soldering section.
i think it's very cool that you want to keep everything as simple as possible.

i'll keep tinkering with the idea for myself, it's a good opportunity to learn.

if it ever works exactly the way i want it to, i will let you know and of course make it available to everyone.

Thank you very much for your help and suggestions.

cecio, 2024-03-29:
Thanks to you!!
And if you have any question, just get in touch.

TryBreakFixAgain, 2024-04-11:
I have taken the liberty to customize the code a bit to suit my needs,

I made all display output quickly configurable with json as I see the use of other languages in my environment.

On top of that I have built a traffic light system.
I am using a Ws2812b DOT (https://www.amazon.com/dp/B088K8DVMQ) on pin 10 (GPIO7).

All changes are documented in the code and can be found via TryBreakFixAgain and tbfa_.

I use ArduinoJson 7.0.4 from Benoit Blanchon
I decided to use the lib and json because I have future changes in mind that I want to make.
Since I am not a programmer, I declare the code as experimental.

 Of course I make the idea and my changes available for adoption into the main code and for general use.

[USBvalveLanguageLightMod.txt](https://github.com/cecio/USBvalve/files/14948277/USBvalveLanguageLightMod.txt)

cecio, 2024-04-11:
Thanks a lot for sharing your work!

As I anticipated, I'd like to keep the build as simple as possible, so I'm happy to keep your mods here if someone wants to use them, but I'd like just to make a super simple mods on the main code to use the on-board led.

Thanks again for sharing this!

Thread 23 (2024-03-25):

Dongle-based devices

Zorakie, 2024-03-25:
Hi, while playing with my USBValve, I found out, that although mice are supported, when I tried connecting my wireless mouse, USBValve does not behave correctly.

Now, I know, that the chance this would be a real world scenario is pretty low, but I want to mention it anyway (what worse can happen than this being closed ^_^

Anyway:
1) When attaching a mouse dongle, there is no USB/HID detection message. Like 90% of time.
2) Those other 10% the Pi "freaks out", sending 4 messages at once, 2 detections, and HID 2 data sending.
3) When attached, no matter what I do with the mouse (movement, clicks, switch off and on again), no message is shown that the device would be sending some info.

So technically, if a malicious device would exist, that mimics whatever protocol is behind this, it would be a potential gap ...

cecio, 2024-03-25:
I don't think the issue is related to "Dongle-based" devices, I tested a lot of them (keyboards, mouse, etc) and they usually works fine.

The point is a bit more complex: the entire USB Host emulation is done via software. This means that timing issues are a thing. TinyUSB suggest to set the clock to 120 or 240 Mhz. But during my tests (done in the last year more or less), I realized that to achieve the wider compatibility I had to tweak this to a specific value, different from the recommended one. With this I have all the devices I ever tested working. But I'm sure that you can stumble in  something not working, or not working all the times like in your case.

I need to figure out a way to debug this without buying all the USB devices available in the world :-)))

cecio, 2024-03-25:
For example, the mouse Jiggler (which is potentially a malicious device) is recognized correctly.

Amyway, thanks for your report. May be I'll ask your help if I need to make some tests ;-)

Zorakie, 2024-03-25:
Consider I know nothing about programming for Pico. Would it be technically possible to change the frequency on-the-fly? I tried a random google search and it seems to be possible (https://www.tomshardware.com/how-to/overclock-raspberry-pi-pico) Would it be possible to change Pico frequency in loops? Let's say 120 to 240, steps per 10MHz, that's 12 steps, it you make it change the freq every 0,33s, you cycle through frequencies each 4 seconds. Considering any HID device would be sending stream of data over time and not like just during one or 2 secs, this could potentially increase detections, as there is a chance you end up on a compatible frequency while the device is pushing something.

cecio, 2024-03-25:
Yes, it is possible, and it is actually what I'm doing now to set the "custom" frequency.

For what regard your idea of "cycling" the frequencies...I'm not sure it is feasible...need to think about it. Thanks for the idea anyway.

Zorakie, 2024-03-26:
Shower thought: How about the "Keep it simple stupid method"? We don't need to loop all the frequencies. What if:

`// Main Core1 loop: managing USB Host
int freqArr[] = { 144000, 230000}; //frequencies to loop
int loopsArr[] = { 50, 100}; //TBD number of loops spent on that freq, lower the freq, in theorz less loops as thez take more time
int index = 0;
int counter = 0;
void loop1() {
    USBHost.task();
    counter++;
    if (counter == loopsArr[index]) {

        index = (index + 1) % 2; //switch to other freq/counter
        counter = 0;
        set_sys_clock_khz(freqArr[index], true);
    }
}
`
If that won't crash the other core while doing stuff, it could - with a bit of luck - work. The only thing to figure out would be a reasonable counter for each freq

cecio, 2024-03-26:
yeah, something like that make sense, but if it works (and I'm not sure, need to test on the field), we also have to consider how to manage the serial monitor (that prints out the activities) which could be broken by these frequency changes, the mass storage emulation, etc. A lot of things to clear out.
I'll look into that.

cecio, 2024-03-26:
First tests are not encouraging: looks like everything breaks :-)))
But I'll keep looking into this.

Zorakie, 2024-03-26:
I am unfortunately 5 days abroad now, but feel free to throw any test build on me, and I can check back on it on Saturday :)

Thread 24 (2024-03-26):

USBvalve PCB with through hole solder points

Manofhunt, 2024-03-26:
I am wanting to build a battery powered version for USB checks on the go. I found a battery component that should work but ideally it would go under the custom USBvalve PCB. Would it be possible to get the original CAD for modification or have a Gerber fileset with through hole configuration instead of surface mount?

cecio, 2024-03-26:
Hey, thanks for you interest in the project.

Unfortunately I don't own the original CAD file, so I can not share it.
I see an issue anyway: if you are going to add headers to the Pico and then solder to the PCB, probably the header of the LCD are not long enough to be soldered (due to the extra space added by Pico the headers), so this modification requires a complete re-design of the PCB itself and the whole form factor.

But I'm wondering:
- if you add headers to Pico, do you really need the PCB? With a small piece of a PCB Matrix board you can probably obtain the same result and be free to arrange your own design
- keeping the current PCB, I think you should be able to reach the power PINs on the opposite side without much trouble

Thanks :-)

Closed 2024-04-05.

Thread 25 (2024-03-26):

ATTiny Attacks / USBkill Attacks

NagelTuev, 2024-03-26:
I have played through a few attack scenarios and am absolutely delighted with the USBvalve.
However, USBvalve did not recognize a Rubber Ducky based on an ATTiny85 in the form of a Digispark Rev.3.

Unlike other Rubber Duckies I have tried, windows does not identify the Digispark as HID but as a USB input device.
USBvalve does not respond at all.

Since Attiny's are very small and very cheap, I see more potential for attack in them than in other Rubber Duckies, simple instructions can also be found very quickly.

Because USBvalve is so cheap to produce, it is the optimal tool that everyone should have.
However, I still see a problem in USBkill attacks,
I think most users will power USBvalve from a computer to check USB sticks.
So the overvoltage from the USBkill would probably still cause damage to the end device.
I'm not an expert on the subject, but I think galvanic isolation would certainly make the project too expensive and complicated.
Possibly a battery could avoid the problem, but I don't know how it reacts to the overvoltage.

I think a note "Supply USBvalve with a powerbank when testing sticks" should be the easiest way.

USBvalve is a fantastic project, thanks for the effort and sharing.

cecio, 2024-03-26:
First of all thanks a lot for your kind words, really appreciated :-)

ATTiny85: I'm aware of this, I bought one of this actually. I don't know if I have a defective device or not, but I barely have it working even on regular USB hardware: most of the times it drops error, it is not recognized at all. I try to flash it, it works one time than it stops again. So, before try to fix it on USBvalve I need to see it working regularly on real USB hardware.
TBH I didn't gave to this high priority so far, but I'll look into that.

Regarding USBKill: I'm not sure what could happen to the upstream device (battery or PC) if you attach a USBkill to the Host port. Probably the "safest" procedure (but I'm not recommending trying it), if you suspect a device is a USBkill, is to attach it to a completely disconnected USBvalve: I assume you will see a flash and some smoke coming out, and then the device will be completely dead. This could be your "canary" :-)

Thanks again.

Himitsu-NL, 2024-04-05:
Hi, not sure if this is helpfull, i bought a couple of ATTiny85 Digisparks ( 4 ) specifically to test the USBvalve, all of them work on the 4 systems i had on hand but are not seen by the USBvalve, the green led's on the Digispark lights up so it does receive power from the USBvalve.
I thought i had made an error in my hardware build before finding this thread.

This is an awesome project, keep up the good work :)

cecio, 2024-04-05:
Thanks for letting me know and thanks for your kind words!

cecio, 2024-04-10:
nice catch @NagelTuev  !
Thanks for letting me know this, I'll try to have a look.

Tz1rf, 2024-04-24:
Has anyone else tested using a power bank or similar device? I had a similar idea about using a power bank instead of a computer as it makes it highly portable and easier to use. So I decided to test this out

If you use a USBValve with a power bank, portable battery or similar device, the USBValve powers on and a couple seconds after I plug a USB Flash drive into the USB A port the screen shows mass storage, then the USBValve turns off. It doesn't appear to cause any damage to the USBValve or the power bank as I am able to repeat the process many times and both are still working. I am curious if others will get the same result or if its something specific to the power bank I am using.

cecio, 2024-04-24:
Some power banks have an auto shout down if the power drained is not enough. Since USBvalve is not requiring a lot of power, may be that's why you see the device going off.

Tz1rf, 2024-04-24:
@cecio

I hadn't thought about that. Let me try another unit and see if I get the same results. I assumed it would work since I use it to power a Raspberry Pi Zero and it will stay powered on until the battery depletes.

frankrpeters, 2024-05-14:
About the USB killers: maybe a few TVS diodes and/or a poly fuse might mitigate that problem? Would at least protect the USB valve itself as well as the connected computer. Would of course be still better if there was a way to detect this.

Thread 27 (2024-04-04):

Buzzer Support?

LiPolymer, 2024-04-04:
Could you please add an optional feature that can notify the user with a buzzer when some suspicious behaviors _(e.g. HID device attached)_ have been detected.
_I'm not an Arduino developer, and I'm sorry I can't help with this amazing project._
(By the way, I designed a dedicated PCB for this project. Can I create a PR when I have tested it?)

cecio, 2024-04-04:
Hey, thanks for your interest into the project  and your feedback :-)

I think the buzzer could be a good idea, but as for another request about an RGB led, I'm a bit doubtful: I'd like to keep the design and build of the main board as simple as possible. Buzzer and additional LED can be useful, but are going to complicate the build process and even if they are not a big issue for someone experienced in building electronics, they can be difficult to manage for novices. So, for the time being, I'll keep this on-hold.

And yes, please if you have a dedicated PCB, open a PR. Thanks!

LiPolymer, 2024-04-05:
Thanks! :)
My PCB is in production.
I'll open a PR if it works well. :D

And about the buzzer, maybe you can make it an **optional** feature. Users can choose whether to weld and use it.  ;)

You can control its pitch by changing the PWM signal's frequency.

I guess that a humble buzzer can make a big difference. :D

Have a nice day ;D

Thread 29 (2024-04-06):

need some pointers please

copywizard, 2024-04-06:
Ok so i got my RP2040 watch from ali everything worked fine out of the box/bag.

But after trying to flash the usbvalve image to it or any uf2 image for that matter the usb device popped up and i dragged and dropped the uf2 on the watch and nothing happened!

So i tried numerous other uf2 files to no avail. now i tried using Arduino IDE to upload the raw data as a sketch and after hours of work i got it to finally upload to the watch i was so happy!

until i saw a black screen and nothing happening on the watch itself i unplugged it and plugged it back in now it identifies itself as a usb drive named MyDrive with two files on it AUTORUN.INF and README.TXT "that says ...nuke the entire site from orbit. It's the only way to be sure."

I really need some pointers if possible? i would love to use the watch as an USBValve.
But why cant i for the love of god not get the UF2 file to flash the device?

I have tried it with a regular pico and rp2040 with all kinds of uf2 images and that works fine!
A few days ago i used this very same setup to flash a PICO with Jrunner to flash my xbox 360 which went very well.
But somehow this device won't work properly.

p.s. using windows 11 also tried using my steamdeck so linux same result the device won,t eject itself after copying UF2 file.

cecio, 2024-04-07:
Hey.

If you managed to get the "Mydrive" mounted, this means that the firmware has been uploaded correctly. Also the file you see are expected and are part of the filesystem itself.
If, despite this, you don't see anything on the screen, there are two possibilities:
- defective device (unlikely, did you see it working with the original firmware? Or can you upload the original firmware to test?)
- the device is not fully compatible with the one I used to create the firmware

Unfortunately there are a lot of different way to wire up LCD to the Pi Pico and if the one you bought is not the same as the one I used to create the firmware, it requires some modification to work.

The best thing here is to obtain the schematics of the connection of your PI watch if available, so we can check the PINs used to connect the LCD and see why it is not working.

copywizard, 2024-04-07:
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

Thanks for the quick reply i didn't expect there would be so much different possibilities for wiring a lcd to a pi pico.

I have added a picture of the labeled pins maybe this could help?

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

I also do not think its a defective device because i worked when i got it in but it would just not accept any UF2 files so i could not flash anything.

today i will try and to upload the original firmware if i can find it somewhere and hopefully i can use arduino ide to upload it i have no idea how to decompile a UF2 to its raw format or if this is even possible?

cecio, 2024-04-07:
Model looks the same as mine.

If you uploaded the firmware through Arduino IDE, you probably re-compiled it. Did you un-commented the following

```
// Uncomment the following to compile for the RP2040 based TFT round display
// https://www.raspberrypi.com/news/how-to-build-your-own-raspberry-pi-watch/
//#define PIWATCH
```

Otherwise you are uploading the wrong version. Anyway, the easiest way is to upload the UF2.

copywizard, 2024-04-07:
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

Thats it i think i just don,t know what i should comment and uncomment?

cecio, 2024-04-07:
```
//#define PIWATCH
```
should become
```
#define PIWATCH
```

Then compile and upload again

copywizard, 2024-04-07:
Nearly there i hope

i have this in there now

#define PIWATCH

#include <Arduino_GFX_Library.h>
#include "background.h"

#else

#include "SSD1306AsciiWire.h"

#endif

and i get this error

exit status 1

Compilation error: #else without #if

cecio, 2024-04-07:
No, you messed up something, it looks like you removed a line.

If you just un-comment that line, you should not get any errror. Start from the clean source and just un-comment line 24.

Then recompile (assuming you are using Arduino IDE with the proper libraries listed in the repo)

copywizard, 2024-04-07:
Copied the code from here

https://github.com/cecio/USBvalve/blob/main/USBvalve/USBvalve.ino

And pasted it in Arduino IDE uncommented the piwatch part

still the same error.

could it be that you say to uncomment "//#define PIWATCH"  but in your own code it says "#if defined(PIWATCH)"

cecio, 2024-04-07:
you are referring to line 31

Look at line 24. Commens in C are not `#` but `//`

So your line 24 should be like this to work:

```
#define PIWATCH
```

copywizard, 2024-04-07:
Damn that did the trick! thanks very much and sorry i think i just can't count :(

Still does not fix the flashing issue but that a whole other problem i have a screen right now!

cecio, 2024-04-07:
Great! Happy it worked! :-)
Thanks!

Closed 2024-04-07.

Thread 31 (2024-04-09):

uf2 file not flashing

Twanaki, 2024-04-09:
Hi,
I'm new to this, so I am probably doing something wrong but I don't know what.
I soldered an I2C OLED screen 128x64 and an USB A port onto a Raspberry pico.
I flashed the blink.uf2 file (from raspberry website) for testing purpose, it works. I simply put file into the mass storage that appeared.
Then I restarted with the BOOTSEL button pressed, and released when the mass storage appeared.
But when I try to flash the USBvalve-0.16.0-64.uf2 file, nothing happen, the folder stays open.
Any help would be much appreciated !

Twanaki, 2024-04-09:
I struggled a lot, but finally managed to get it work by installing Arduino IDE and everything necessary, and then flashing from there.

cecio, 2024-04-09:
Strange. I just tried to do the same, but it worked fine on my system.
I'm not sure what was causing the issue, but happy you managed to find out the solution.
Thanks for the update

Twanaki, 2024-04-10:
I don't know why it wasn't flashing on mine. I bought the Pi Pico on Amazon from a random seller.
Thanks for your tool, it's fantastic !

Zorakie, 2024-04-10:
Maybe it is lost in translation, but from what you wrote, I have an impression that you may be putting the file to a wrong storage.

There are 2 storages:
1) when you have this project running, it shows a storage with some content, but that is basically fake.
2) The storage where you need to upload the binary file is the one with BOOTSEL.

Maybe that behaves differently the first time ever the pico is started, but generally, you should:
1) Unplug pico
2) Hold BOOTSEL while plugging the microusb cable to your computer. Don't release the button until the pico is plugged in and the storage shows
3) storage should pop up (pico is now in the setup mode)
4) upload file there, the pico should automatically restart
5) unplug it and plug it again
6) TADAA, you should be running USBValve

DFranzen, 2024-04-13:
I am having the same issue. Tried via the usb storage and also via picotool, but no luck so far.
The example blink.uf2 flashes successfully, but with usbvalve the usb storage never unmounts and the raspberry does not reboot. Upon manual reset after several minutes of inactivity, it just goes back to the previously uploaded program.
I am using this unofficial rp2040 board, which has a usb C port and also an on board RGB LED, so would he pretty nice to have usbvalve running on it: https://www.aliexpress.com/item/1005006051120831.html

DFranzen, 2024-04-13:
Quick update, I thought to check a previouse version: version 0.16 flashes successfully in the normal way.

Zorakie, 2024-04-13:
Maybe there is something wrong with the unofficial board... jumping here just to confirm back that for official Pi Pico board, everything seems to be working. I have just flashed 0.17.0 via BOOTSEL/directory with no issues 🤷‍♂️

cecio, 2024-04-13:
Thanks for the test @Zorakie

@DFranzen it sounds really strange. The presence of RGB LED on the unofficial board open to some possibilities, like incompatibility of the used PINs etc, but despite this, you should be able to flash: then may be the board does not work, but at least it should load the firmware and reboot.

DFranzen, 2024-04-23:
Another quick update, might be able to help others with this issue:
The uf2 file that is available in the Releases-Section on Github (V0.17) does flash and runs without any problems. The one I tried before is the one in the folder structure in the folder "firmware" (as described in the README). That one still does not flash. Indeed they have two different hashes:

$ shasum USBvalve-0.17.0-32_*
1760708087fd7cf4a5e6bac86bc7baa35600f0cd  USBvalve-0.17.0-32_release.uf2
6869c877579ffc58305fbc49b9a251c3a3b109ff  USBvalve-0.17.0-32_tree.uf2

Is that difference intended?

cecio, 2024-04-23:
That's weird: tbh I tried to replicate this, but now way:
I tried to download the file from the Releases, clone the repository, download it from the firmware folder, and I get always the same hash `1760708087fd7...`

Could you please check size and content of the other one? I don't understand from where is coming.

cecio, 2024-04-23:
are you sure that you downloaded it in the proper way? For example, going with the browser in the `firmware` folder and right-click on the file name and doing a "Save Link" is going to save an HTML doc, not the firmware file.
Please check the content of the not working file, I'm pretty sure it contains something unrelated.
Also, the fact that it is named `_tree` is suspicious.

Tz1rf, 2024-04-24:
@cecio
For what its worth I also cannot replicate this problem. I can also confirm that there is nothing wrong with the firmware downloads. No matter how I download them they are the same.

Anyhow @DFranzen

Did you purchase the USB-C 4MB version? If so the following steps must be performed to load firmware on this unofficial Pico. As previously stated, the firmware should load and reboot. Probably useful for others that decide to go this route and purchase the unofficial Pico.

1. Connect the Pico to your computer
2. Long press the BOOT button
3. Press the RST button
4. Release the BOOT button after 1 second;
5. If dont correct, the computer should show the storage on the Pico as a hard disk
6. Copy the firmware file for USBValve to the pico and it should automatically reboot.

cecio, 2024-04-24:
thanks @Tz1rf

DFranzen, 2024-04-24:
Yes, I am sorry, I did not realize, that Right click -> save as, does not download the raw file, but an HTML-page. Maybe that's also what happened for Twanaki? Recompiling the firmware using the Arduino IDE, as they did, would also have solved my oversight.
Thanks for your help and time on this and generally for your work on this awesome project.

Can I suggest, in order to give this issue a constructive solution, to add a link to the Release page (https://github.com/cecio/USBvalve/releases) in the Readme-file in the instructions on "Flash Firmware".

Twanaki, 2024-05-14:
Hi guys,
You are right, I did the same mistake with right click and save as. Apologies.
Because the downloaded file is .uf2, I thought it was ok.
Sorry about this, have a nice day !

Closed 2024-05-19.

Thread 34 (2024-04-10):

Pico with built in display and usb-c

SeventhDread, 2024-04-10:
I’m quite interested in making my own USBValve and I’ve found this pico on Amazon https://amzn.eu/d/6Hgc5Mu would it work?
It has usb-c which is what I was looking for and a built in bonus IPS screen.

I also don’t like soldering I always make a mess of it so less is better so I would thinking I could get this but with the pin headers, I have cables that can connect to the pin headers then connect the correct pins to a usb a port and then try to 3D print an enclosure to hold it all. Is there anything I am missing or could this work?

Thanks!

SeventhDread, 2024-04-10:
Also building on this I was thinking of having usb an and usb c host ports would having both work with this? I saw in another post you said you could do it just one would work at a time, how would you wire this up?

And just being curious not related to what I’m asking what these detect cables like the hak5 O.M.G ones? And I’m guessing cables like them could be detected through either port (host or pico power port)??

cecio, 2024-04-11:
Hey @SeventhDread

Thanks for your interest in the project. I try to address your questions below:
- the problem with all the Pi pico based boards out there is the LCD. You can try, but I'm pretty sure it will not work. Usually is not so hard to fix (you need to understand which is the LCD controller and find the correct wiring in terms of PIN),  but it will not work with  the provided firmware
- if you want to connect two different USB Host ports, you can do it, even if it is not really supported, especially because you are going to connect to the same PINs. You have to be careful because inserting two devices at the same time could potentially create damages, unless you put some diode/resistors on the connections
- I'm not sure about the Hak5 cables, never tried. If they act as HID, Mass or net devices, yes. If they are just hubs, may be not. If someone have one of these cables, I'm interested in knowing what happens when one is connected

Thanks,

SeventhDread, 2024-04-12:
Thanks for getting back to me! Seems the pico with a screen might just make things too complicated. Ill just go the normal route. Thanks, can't wait to make my own!

Closed 2024-04-20.

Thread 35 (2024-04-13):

[Enhancement] Write dump

Zorakie, 2024-04-13:
Hi,
This idea is probably one of the more complex ones:

It would be great to log possible read/write actions.

So basically:
1) Add a Card reader slot support (Quick search and it should be technically possible (https://www.youtube.com/watch?v=rr_JQchpa1Q)
2) On power up, mount the SD
3) If the device tries to write something through main (Micro/C) port, redirect it to the SD.
4) If the device on the USB-A port starts sending some data (HID), create a text file with random name and write the inputs.

That would help us to understand not only if the device is sending some data, but later on, we can remove the SD, put it into PC and find out, what has actually happened.

for MVP:
1) Fixed size card
2) Predefined format (FAT32).
3) On boot, check if card is inserted to enable logging
4) random name (as pPico does not have clock), only when creating files, prepend "host_" or "valve_" so we know through which end it came (and on PC, we then always can filter by file creation date)

Let's see, I have no idea how hard this would be even with borrowing some existing Pico SD project, and also I am not sure if the limited processing power of Pico would allow it, but anyway, it would be cool :)

cecio, 2024-04-13:
Thanks @Zorakie , it is a very interesting idea indeed.

And partially, it has been implemented in some way: if you connect the serial port created by USBvalve, you'll see that a partial dump of the disk operation is already printed out. Right now it is partial because the output on the serial is quite expensive and impacting timing of other operations.

But I think that it can be de-synched and probably managed completely: in this case if you log the serial output you may have the complete dump of the operations.

Adding and SD card is another option and it is feasible for sure, but it would require some redesign of the entire project. May be it could be  a mid-long term project.

Anyway, thanks for your suggestions, they are always interesting!!

Tz1rf, 2024-04-24:
Any reason this cannot just be logged to the nearly 1MB of free storage the Raspberry Pico already has? The storage that shows up when plugged into the computer and has a txt file already created in there that says nuke the entire site from orbit. Text files are extremely small so the 1MB storage should be plenty to lot a read out of read/write operations

Zorakie, 2024-04-24:
@Tz1rf
afaik, and cecio will correct me if I am wrong, that storage that you see normally is not a real storage, but rather a view of pico RAM. If you check the source code, those files are created in memory on startup, so once you unplug the pico, that memory block size to exist, which would include anything you would "store" there.

cecio, 2024-04-24:
what @Zorakie  says is absolutely correct.

@Tz1rf there are at least 2 reason for not using the internal USB storage:
- I need to monitor the activity on the drive at very low level, and I don't think it's possible without creating a "fake" layer with a storage on it
- in order to avoid to spread malware through USBvalve (which would be a shame ;-) ) everything is in RAM and destroyed at each unplug

Tz1rf, 2024-04-24:
@Zorakie

This is why I suggested this storage space. I apologize if I described it incorrectly and caused a misunderstanding

@cecio
I suggested the storage space for the reasons you pointed out. Its okay if the txt file is destroyed at each unplug. I wouldn't change this as its an appropriate air gap to prevent malware from spreading.  Or am I misunderstanding something here?

Zorakie, 2024-04-24:
Well, here is the problem: 1MB is enough for such scripts, sure. But the idea behind the dump is, you want to store the data on the go, then remove the card where you know you have a safe .txt dump, and review later.

Also the malware spreading is a valid thing.

And really, 90% of time, you will be somewhere outside, testing if some shopping mall charger is not trying to spoof your phone or something.
And even for USB-A testing, I would feel more safe running Pi from powerbank rather than testing on my PC (If I stumble upon killer USB, I will rather blow my 20€ pico project and 30€ powerbank rather than my 2300€ rig... 🤷‍♂️

cecio, 2024-04-25:
@Tz1rf sorry, I misunderstood your question. You are proposing to use the on board USB Mass storage device, just for logging purposes, correct?

If so: this area is accessible only in BOOTSEL mode from what I see, and it is not accessible in other ways. But I'll try to dig a bit more. The other accessible area is the flash, but it's small and not accessible as filesystem.

TryBreakFixAgain, 2024-05-14:
If added a SD-Card Logger on my Mods, Works like charm.  ;)

cecio, 2024-05-14:
oh wow, great job!!

Tz1rf, 2024-05-14:
@TryBreakFixAgain What is it able to log?

I am very interested. If a custom PCB can be developed to use this SD Card add-on, I will make a new video showing how to build this. I wish I could help but I do not know much about creating gerber files for PCB, but based on the current one I would imagine adding the SD Card add-On to the back of the PCB with holes between the USB A Port and Screen might work.

TryBreakFixAgain, 2024-05-15:
@Tz1rf At the moment I write out the complete serial output to a static text file called datalog.txt, including a display warning if it is larger than 5mb at startup. I still have to improve the complete handling of the log files, but I am encountering some problems, so I have published this status for now.  A custom PCB should not be a problem, you can find all necessary infos in the readme of my fork in the point mappings. I will publish a log of an attack in the project wiki later today.

Tz1rf, 2024-05-15:
> @Tz1rf At the moment I write out the complete serial output to a static text file called datalog.txt, including a display warning if it is larger than 5mb at startup. I still have to improve the complete handling of the log files, but I am encountering some problems, so I have published this status for now. A custom PCB should not be a problem, you can find all necessary infos in the readme of my fork in the point mappings. I will publish a log of an attack in the project wiki later today.

Thanks for the additional information. Is the problem you are encountering have to do with the limited processing power of the Raspberry Pico?

TryBreakFixAgain, 2024-05-15:
@Tz1rf  not only, some limitations are based on the SD lib its a hard combination for me, im only a beginner with microcontrollers and coding, and my free time is very limited

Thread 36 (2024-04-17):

3D Printable enclosure for 128x64 screen version

rtmq0227, 2024-04-17:
Since the only enclosure in the repository is for the smaller, x32px screen, I put together an option for the larger x64px screen (stl files attached).  It assembles with six M2x18 screws with room for locking nuts (links below), and some rubber padding to seat tightly without rattle.  It's designed for Resin printers, so you may need to file down and drill out the interior openings if you have a pronounced foot on the print.  I also recommend not soldering the screen to the PCB until you have it in the enclosure for the fit to be right.

STL Files: https://www.dropbox.com/scl/fo/kd9u046t1vtf3h2jkpmb5/ACpoGzTPq_6m6kwyjEtopGc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
Screws: https://tinyurl.com/mry88wyv
Nuts: https://tinyurl.com/yhzkmhmj
1mm Rubber Sheeting: https://tinyurl.com/4775dfs5

cecio, 2024-04-17:
oooh wow!! It looks awesome, thanks!!
I'll try to print it, even if I don't have a resin printer, let's see how it works.

rtmq0227, 2024-04-17:
I found the most success avoiding the elephant's foot issue ruining the face of it by orienting the main stl as shown (text facing up) but it does require supports on the underside in that case.  I originally designed it to print the opposite way but couldn't reign in the foot on my printer

rtmq0227, 2024-04-18:
I added a "simple" STL package for if the fiddly bits are too much for a filament printer.  I also added some better pics to showcase the final build better

Manofhunt, 2024-04-18:
I printed the original case on my FDM printer and the only issue I ran into is the holes for the nuts were a little tight. I was able to chamfer the holes with a razor blade and that solved the issue. Thank you for providing these!
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

rtmq0227, 2024-04-18:
I'll admit I ran my tolerances a bit tight, I'm printing on a Photon Mono X.  I can adjust the "simple" version to add a little more room for the nuts, how much extra clearance did you need to add?

Manofhunt, 2024-04-18:
Difficult to say since I did it by hand, but probably about 0.5mm cumulative between the different sides I shaved on each nut location.

cecio, 2024-04-18:
@rtmq0227 thanks for your work on this.
If it's ok for you, I'd add the files to the repo.
Thanks!

rtmq0227, 2024-04-18:
Gladly!

I'll update the simple files with the expanded nut holes tonight

rtmq0227, 2024-04-19:
Okay, I've added a v1.1 for the simple backplate with larger holes for the nuts, and here's an orientation guide (since Fusion always seems to export in the wrong orientation -__-)

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

cecio, 2024-04-19:
thanks @rtmq0227
One question: am I wrong or in the new folder I see two version of the backplate but no spacer?

rtmq0227, 2024-04-19:
no, there should be all three. I removed the old version so now there's only three STL files in each version's folder

cecio, 2024-04-19:
ops, sorry. Thanks, I included your STLs in the STL folder and credited in the README.
Thanks again for your contribution.

pettard, 2024-04-25:
Really nice looking case! would it be an idea to also make a top plate for the 128x32 screen?

rtmq0227, 2024-05-01:
> Really nice looking case! would it be an idea to also make a top plate for the 128x32 screen? @rtmq0227

I wasn't going to, as there's already an enclosure STL for the 128x32, but a coworker was having trouble with that one so I may as well (better to have more options than fewer, right?).

It'll take time as I'll have to put together one with the smaller screen for reference purposes.

Tz1rf, 2024-05-13:
@rtmq0227

Where did you make use of the rubber sheeting on the enclosure? Does it go between a layer?

rtmq0227, 2024-06-26:
@Tz1rf sorry for the delay in responding!  I use it between the middle layer and the PCB to take up the gap/tolerance and keep it from rattling around.  A small strip along each of the longer sides of the PCB do enough without messing with the ventilation.  I'll be doing an assembly video in the near future, but I'll try to get some pics for this thread in the meantime.

pettard, 2024-07-17:
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

@rtmq0227  if you want me to test out the design i would be happy to do so.

rtmq0227, 2024-07-17:
@pettard So I actually did recently put one together, but the current STL has a second hole for a NeoPixel because I was trying to create a custom build with a color-coded indicator to match the events (green, yellow, red, flashing red).  I'll create a version without the extra hole and share it here soon.
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

rtmq0227, 2024-07-17:
@Tz1rf here's that image I promised:
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

pettard, 2024-08-12:
@rtmq0227 Any update on the 128x32 version?

rtmq0227, 2024-08-13:
> @rtmq0227 Any update on the 128x32 version?

Sorry, I lost a lot of personal bandwidth in preparation for DEFCON

Here's the STL of my x32 screen enclosure.  It works with my existing spacer and backplate STL files: https://www.dropbox.com/scl/fi/oqpq88l8r2xmb2uyov4sn/Enclosurex32-Final.stl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

Mikitwin, 2024-12-30:
For those who don't have a 3D printer, JLCPCB can make the USBvalve PCB as well as the enclosure (JLC3DP) at a very low cost. The only problem that I had is that, to avoid cracks or deformation, they ask for a minimum of 0.8mm wall thickness with the resin (Black resin) and the printing technology (SLA) I chose. The customer service is really nice so they warn you and ask for confirmation before they do the fabrication if this happens. For the 1.2_64 design for example, they sent me this thickness analysis:
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

To be safe, I switched to the 1.2_64_simple design but the screw holes were also too thin on that design. I accepted the risk and the result was still very clean!
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

With all that said, a possible improvement would be to update the designs so that there are no sections under 0.8 or 1 mm. This way people could order from JLC3DP without any issue. I'm afraid I'm not good enough in 3D design to make the changes myself. That's why I am very grateful that people provided designs for the enclosure!

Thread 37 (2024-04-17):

Debugger on the pcb version

iamagithublearner, 2024-04-17:
How do you use the debugger on the pcb?
i see that there are solder points for connecting pico's debug pins to the pcb, but how do you use those?

Closed 2024-04-20.

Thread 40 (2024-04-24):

display not showing proper info

Drmalkav, 2024-04-24:
hi there, i tried to build this yesterday, but i can't get the display to show the proper text. I can only manage to get characters in the first "column" (pic1) i have tried to flash a couple of older versions too, but no difference. I'm pretty sure i've flashed it properly, because when i edit the readme file it gives me more characters on the screen (pic2). I'm still very new to the pico and i'd be gratefull for all help or tips you all have.
Sincerely, Henrik
ps- i haven't installed a female usb a to the bord, as i wasn't planning on testing bad usb drives yet.

 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

IAmOrion, 2024-04-24:
I would suggest first running an I2C Scanner sketch to double check the I2C address of the OLED module.  The firmware uses 0x3C - it's possible your module uses a different address

Also double check the SDA/SCL connections are the correct and not the wrong way round.

Tz1rf, 2024-04-24:
@Drmalkav
Can you please confirm wires are soldered on the correct pins?
PIN6 of Pi --> OLED SDA
PIN7 of Pi --> OLED SCL
PIN38 (GND) of Pi --> OLED GND
PIN36 (3V3OUT) of Pi --> OLED VCC

Drmalkav, 2024-04-24:
They are I triple double checked, even tried to reverse them as suggested.
I'm currently trying to figure out how to do the i2c scanner

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

Drmalkav, 2024-04-24:
> I would suggest first running an I2C Scanner sketch to double check the I2C address of the OLED module. The firmware uses 0x3C - it's possible your module uses a different address
>
> Also double check the SDA/SCL connections are correct and not the wrong way round.

i got the scanner working on a Arduino nano, it says
```
Scanning...
I2C device found at address 0x3C  !
done
```

cecio, 2024-04-24:
mmmmh....really strange.
Could you try to re-solder the wires? May be a cold solder joint or a defective wire...it seems strange, but other than that, the only thing that remains is a defective screen. Did you tried it with other software?

IAmOrion, 2024-04-24:
> already tried resoldering, im waiting on some more screens in the mail, so i'll re test with those. Do you maybe know of some other software i can use to test my current display?

Try running the Adafruit SSD1306 Example "ssd1306_128x64_i2c" and see if that displays as expected.  If you don't have the library, you can install it via Arduino IDE or here: https://github.com/adafruit/Adafruit_SSD1306

You will need to change ```#define SCREEN_ADDRESS 0x3D``` to ```#define SCREEN_ADDRESS 0x3C``` on line 35

Tz1rf, 2024-04-24:
@Drmalkav

Just for testing purposes did you try flashing the firmware for the smaller screen? It should still display text, it will just be larger and a bit pixelated.

Drmalkav, 2024-04-24:
@IAmOrion thx for that, i can now confirm, that my display works perfectly well :)
@Tz1rf  yup that looks like this
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

Tz1rf, 2024-04-24:
Is this another unofficial Pico? Looks like a USB-C Port on there.

IAmOrion, 2024-04-24:
With USB-C that has got to be a clone, in which case the pre-built firmware may not work if the SDA/SCL pins are not broken out on the same GPIO/Pin numbers.

Drmalkav, 2024-04-24:
oh dang, i thought i had bought an original with just a type c port plopped on for convenience. Is there any way to figure out what the pin breakout is?
this is the description the seller posted
`Raspberry Pi Pico Board RP2040 Dual-Core 264KB Low-Power Microcomputers High-Performance Cortex-M0 Processor

Specification:

• RP2040 microcontroller chip designed by Raspberry Pi in the United Kingdom • Dual-core Arm Cortex M0 processor, flexible clock running up to 133 MHz • 264KB of SRAM, and 2MB of on-board Flash memory • Castellated module allows soldering direct to carrier boards • USB 1.1 with device and host support • Low-power sleep and dormant modes • Drag-and-drop programming using mass storage over USB • 26 × multi-function GPIO pins • 2 × SPI, 2 × I2C, 2 × UART, 3 × 12-bit ADC, 16 × controllable PWM channels • Accurate clock and timer on-chip • Temperature sensor • Accelerated floating-point libraries on-chip • 8 × Programmable I/O (PIO) state machines for custom peripheral support

Informaiton:

You can get more information for the Raspberry Pi Pico by this link or click the photo:`

IAmOrion, 2024-04-24:
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

Please provide a link to the product page from which you purchased this item

cecio, 2024-04-25:
[firmware.zip](https://github.com/cecio/USBvalve/files/15107551/firmware.zip)

@Drmalkav
Could you try this version of the firmware? Unzip and load as usual. Thanks!

Drmalkav, 2024-04-25:
@IAmOrion this is where i bought it [aliexpress](https://www.aliexpress.com/item/1005006122200429.html?spm=a2g0o.order_list.order_list_main.84.e44d1802KcxBLG)

@cecio i got no image with that one.

Thank you everyone for your help and suggestions. I think i'll have to throw in the towel, and order a original board from a authorized seller.

tvandoorn, 2024-04-25:
Hello,

I don't mean to hijack this issue, but if @Drmalkav is giving up on this I wouldn't mind to keep trying. I am facing the exact same issue, but I am using the PCB, together with a Pico from [here](https://www.aliexpress.com/item/1005003371056277.html) (Color: Green), and a display from [here](https://www.aliexpress.com/item/1005005970901119.html) (Color: SSD1306 Y B).

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

I have tried the following so far:
* Running the 128x32 firmware
* Compiling the firmware myself using the Docker image
* Changing the I2C_ADDRESS to 0X78, 0X7B and 0X7A (based on what the back of the display says)
* The firmware made by @cecio

I can confirm the screen works by loading MicroPython on the Pico and running the following:
```
import machine
import ssd1306
from time import sleep

i2c = machine.SoftI2C(scl=machine.Pin(5), sda=machine.Pin(4), freq=400000)

print('Scan i2c bus...')
devices = i2c.scan()

if len(devices) == 0:
  print("No i2c device !")
else:
  print('i2c devices found:',len(devices))

  for device in devices:
    print("Decimal address: ",device," | Hex address: ",hex(device))

oled_width = 128
oled_height = 64
oled = ssd1306.SSD1306_I2C(oled_width, oled_height, i2c)

oled.fill(0)
oled.text('Hello, World 1!', 0, 0)
oled.text('Hello, World 2!', 0, 10)
oled.text('Hello, World 3!', 0, 20)
oled.show()
```

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

The code above also prints the following I2C device information:
```
Scan i2c bus...
i2c devices found: 1
Decimal address:  60  | Hex address:  0x3c
```

cecio, 2024-04-25:
Could someone try the `HelloWorldWire.ino` sample from https://github.com/greiman/SSD1306Ascii ?
Thanks

IAmOrion, 2024-04-25:
For what it's worth, I have an official raspberry pico, the UF2 firmware also did NOT work for me - I didn't get anything on the display at all.

I used the Adafruit 128x64 I2C demo to make sure my OLED was working using 0x3C address and it was.

I then opened the source and uploaded directly to my Official Raspberry Pico using Earl Philhower's boards (https://github.com/earlephilhower/arduino-pico) and it worked without any changes.

So for whatever reason, the supplied compiled UF2 file found in firmware folder https://github.com/cecio/USBvalve/blob/main/firmware/USBvalve-0.17.0-64.uf2

did NOT work for me, but opening the .ino file found in https://github.com/cecio/USBvalve/tree/main/USBvalve (obv downloaded everything first, unzipped, then opened the ino from that folder) then uploading to my pico worked perfectly

Drmalkav, 2024-04-25:
@cecio here u go
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

@IAmOrion just tried to follow your latest post, but got the same usual result

IAmOrion, 2024-04-25:
> @cecio here u go ![IMG_20240426_012117](https://private-user-images.githubusercontent.com/41089048/325796333-b02c54be-cf0b-4208-9dcf-280372d70304.jpg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)
>
> @IAmOrion just tried to follow your latest post, but got the same usual result

You have the IDE & All libraries and board stuff installed? Have you got anydesk?

tvandoorn, 2024-04-26:
> Could someone try the `HelloWorldWire.ino` sample from https://github.com/greiman/SSD1306Ascii ? Thanks

I'm also getting just the exclamation mark on the screen with this example. When I replace `oled.print("Hello world!");` with the code below I only get the letter "o".
```
oled.print("H");
oled.print("e");
oled.print("l");
oled.print("l");
oled.print("o");
```

Looks like it only displays the last character of whatever is written to the display.

cecio, 2024-04-26:
Thanks to all for the tests.
From what I read it seems that the library used is not compatible with all the screen out there. I'll try to change something and see if I can improve compatibility.

cecio, 2024-04-27:
If someone have time do to a test:
[firmware.zip](https://github.com/cecio/USBvalve/files/15138135/firmware.zip)
It will probably not work, but I'd like to understand if the problem has something to do with the fonts.
Thanks

tvandoorn, 2024-04-27:
Hi, this is what it displays on the screen:
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

Drmalkav, 2024-04-27:
@cecio i get the exact same result with that firmware as @tvandoorn does.

@IAmOrion my soldering definitely needs improving xD but i can happily confirm, that there are no shorts :)

cecio, 2024-04-27:
thanks @tvandoorn @Drmalkav  , so it seems fonts are not the root cause :-)

cecio, 2024-04-27:
Tried to change something:
[firmware.zip](https://github.com/cecio/USBvalve/files/15139669/firmware.zip)
just check if display work, functionalities are not complete.
Thanks

tvandoorn, 2024-04-27:
Looks like you're onto something here 😁
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

Drmalkav, 2024-04-27:
Yup definitely did something
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

cecio, 2024-04-28:
This should be a working release for 64 lines screen:
[firmware.zip](https://github.com/cecio/USBvalve/files/15141888/firmware.zip)
If someone can test it a bit it would be great. Next week I'll be a bit busy, so I will not make a new release, but if everything is fine, the week after I'll include this in the official branch.
Thanks

Drmalkav, 2024-04-28:
@cecio thank yoi so mich :) seems to work perfectly, it detects when I read the readme and when I write anything. I don't have a bad usb so can't test that part, but everything else looks awesome :)
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

tvandoorn, 2024-04-28:
Yep, it's also looking good here. I haven't received my USB port component yet so I cannot test bad USB, but I'll let you know once I do.

Thanks for your time and effort! Looking forward to seeing what caused this issue.

cecio, 2024-04-28:
Thanks to both @Drmalkav  @tvandoorn
The issue was basically an incompatibility of the library I was using. I switched to a different one, but it was a bit longer because I had to implement some function not implemented in the new one (like scrolling).

Closed 2024-04-28.

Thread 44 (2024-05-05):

Button Press Required on Boot?

Hephalumpo, 2024-05-05:
Hi There, I absolutely love the USBvalve! I have mine mostly working but each time I power it up I have to press the "reset" button before the screen will turn-on. Is this part of the design, and if so is there a workaround? Or do you think I've missed a solder somwhere?

Thank you so much for developing this project :o)

NagelTuev, 2024-05-05:
it shouldn't really be like this, re-solder all the soldering points and flash the valve again

cecio, 2024-05-05:
Hey @Rae-Hughes thank you very much for the kind words!

No, this is not expected. It should start without pressing reset. What @NagelTuev (thanks!) says is correct.
If it does not help, please provide some more info:
- firmware version
- LCD version (32 or 64)
- Pico Board used (official model, clone, other....)
- LCD hardware used
- did you wired your connections or used the PCB?

Thanks,

Rae-Hughes, 2024-05-05:
Hi Folks, thank you so much for getting back to me so quickly! I'll re-solder and get back to you. My soldering skills aren't great so I thought that might be the issue

Rae-Hughes, 2024-05-08:
Hi hi,

So I started again, fresh PCB, New Pico, new OLED, new USB port. Soldered everything. Flashed the Pico. Yet I still have exactly the same issue. I need to press the button to get the screen on when I first power it up.

Any thoughts?

cecio, 2024-05-08:
Which firmware version are you using? The latest? Could you try to flash an older one, like 0.17.0 and/or 0.16.0?
Also, is your Pico a standard one or a clone? Some of the clones has additional features that can introduce incompatibilities.
Thanks,

Rae-Hughes, 2024-05-09:
I tried flashing with both 0.17.0 and 0.16.0 and they both had the same issue. My Pico is a standard one as far as I'm aware

cecio, 2024-05-09:
mmmmhhhh...weird...
Let's try to recap:
- you insert the cable in the Pico micro USB
- then you connect the cable to the PC
- you don't see anything on the screen nor a device is mapped on the PC
- then you press reset
- at this point the screen turns on and you see a mapped device on the PC

Could you confirm that this is what is happening?

Rae-Hughes, 2024-05-10:
So what happens is,

- I insert the cable into the Pico micro USB
- I connect the cable to my PC
- I see a mapped device on the PC as normal (with the .txt file, etcetera)
- The screen shows nothing
- I press the reset button
- I see a mapped device on the PC *and* the screen turns on and then functions as normal

cecio, 2024-05-10:
which is the model of the screen you are using? Do you have a link ?

Rae-Hughes, 2024-05-11:
Hi, I'm using this,

https://www.diymore.cc/products/diymore-0-91-inch-iic-i2c-oled-lcd-12832-128x32-display-diy-module-ssd1306-driver-ic-dc-3-3v-5v-stm32-for-arduino-pic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

cecio, 2024-05-12:
Can you try the following firmware and let me know if it works?

[firmware.zip](https://github.com/cecio/USBvalve/files/15285714/firmware.zip)

Thanks,

Rae-Hughes, 2024-05-15:
Hi hi,

The firmware does function, but it doesn't solve the issue with the button..

TryBreakFixAgain, 2024-05-15:
i ran into the same problem and realised that it was sometimes due to bad connections, but also partly due to the power supply, especially with the very cheap displays.

how do you connect the display to the pico? by cable, pcb or breadboard? Maybe your cables are not in good condition, or the pcb. you could use a multimeter to check the continuity and the resistance of the connections, with the short cables there should be almost no resistance.

Rae-Hughes, 2024-05-16:
I'm using a PCB, so maybe it's that? But it's a well-built PCB..

I might have to invest in a better OLED

TryBreakFixAgain, 2024-05-16:
Do you know how to use the arduino ide? install the adafruit ssd1306 library, in the examples you will find the ssd1306_128_32_i2c.ino install it on your pico. if it gives the same error, it is the hardware.

if you can't get it to work, let me know and I'll build you the firmware quickly.

alternatively you can also try to solder the display with cables to test if it's the pcb. But I think it's more likely to be the displays.

Hephalumpo, 2024-05-16:
I tried, and was unsuccessful. If you've got a version of the firmware I could download that would be super helpful

TryBreakFixAgain, 2024-05-16:
[ssd1306_128x32_i2c.ino.zip](https://github.com/cecio/USBvalve/files/15338862/ssd1306_128x32_i2c.ino.zip)

no problem ;)

Hephalumpo, 2024-05-16:
Thank you so much!! I have the same issue, the screen doesn't light when I plug the pico in

TryBreakFixAgain, 2024-05-16:
Sounds like hardware issue, do you get something somehow, or nothing at all? if u get nothing your displays could use an other I2C adrress, but i dont think so

Closed 2024-07-06.

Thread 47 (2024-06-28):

USBvalve not visible from pc

iali9906, 2024-06-28:
my USBValve is not detected by the pc.

here are the steps of what happens:

1) plug the cable into the Pico micro USB
2) then connect the cable to the windows 11 pc.
3) nothing appears on the pc
4) "USBvalve - 0.13.0 - [+] Selftest: OK" appears on the lcd.

i tried to flash new firmware, but by holding down the reset button "[+] RESETTING" appears and stays fixed on the lcd without showing anything on the pc. if i instead click it once the reset word appears and reappears right away, but nothing changes.

Thanks

cecio, 2024-06-28:
Hey.

Strange issue: I'm not sure if you tried to put the device in BOOTSEL mode. To do it, you have to unplug the USBvalve (Pico), hold down the BOOTSEL button and plug the cable in.
If you did it right, you should see a new device on the PC (named RPI-RP2) and the LCD should remain off.
In this mode you can test if your Pico is working or not.

Other random things to check:
- if the cable is a data cable (some of USB cable are just for power)
- if your PC has any security software or setting blocking the usage of USB devices

Closed 2024-07-21.

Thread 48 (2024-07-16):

printf errors when compiling in Arduino IDE 2.3.2

rtmq0227, 2024-07-16:
I'm trying to add some features to the current build (ARGB/NeoPixel support) and after configuring the IDE with the libraries and versions you listed, I keep getting an error on the serialtinyusb.printf() calls, suggesting I use print instead.  Is there another version of tinyusb you're using or any custom source files you may have injected?  I already had to add the stdlib.h and stdio.h files to Pico Pio manually as they are no longer included in the package the IDE downloads.

cecio, 2024-07-16:
hey.

No, I don't recall any other library added to the environment. It's strange that you had to add that header files, this is a sign that something is wrong, may be some conflicts between libraries.
To install Pico PIO USB you should add it to Library Manager (https://www.arduino.cc/reference/en/libraries/pico-pio-usb/). Remember to use version `0.5.3` and not the latest, which is causing some issues.

To simplify things, you can use the docker file to compile, it should download and build the correct environment, you can follow instructions in the README for that.

Cheers,

cecio, 2024-07-17:
I tried to make a new installation of the IDE from scratch.
The only thing  I had to manually modify was to add

https://github.com/earlephilhower/arduino-pico/releases/download/global/package_rp2040_index.json

in the `File-->Preferences-->Additional Board Manager URLs` in order to be able to install the proper board (`Raspberry Pi RP2040 (3.9.3)`). Then I just added the libraries with the library manager (installing with dependencies) and it worked, without modifying anything else.

Let me know if this helps.
Cheers,

rtmq0227, 2024-07-18:
That absolutely did the trick!  Thank you so much for checking back in on this.

Now I need to figure out why the Adafruit_NeoPixel code I added is crashing the device, but that's an issue for another time.... :)

Closed 2024-07-18.

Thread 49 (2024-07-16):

Screen not working (black dots and white lines)

markthwain1797, 2024-07-16:
Me again,
this is my first breadboard build an I never really used microcontrollers before, so please don't be harsh.

I got [this screen](https://www.az-delivery.de/products/1-3zoll-i2c-oled-display) in addition to a rasperry pi pico.

My screen looks like the following is no device is connected vs if a bad usb is connected:
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

I'm not exactly sure I'm on the right path, but my research showed it might be a problem with getting the right driver for "cheap" OLEDs: [Link (reddit)](https://www.reddit.com/r/esp32/comments/10v4dmr/comment/j7fegwj/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)

Any help or suggesting is very appreachiated. Thanks in advance.

cecio, 2024-07-16:
Hey.

Which firmware version did you uploaded? With this screen you should use tge 64 lines version:

`USBvalve-0.18.2-64.uf2`

or if you are compiling from code, you should change line 86 from

```
#define OLED_HEIGHT 32
```
to
```
#define OLED_HEIGHT 64
```

markthwain1797, 2024-07-17:
Hi, thank you :)

I actually tested both versions. The pictures above are from the 32 lines version.

If I use the 64 lines version the screen looks like this (without and with bad usb)
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

cecio, 2024-07-17:
Yes, it looks like a compatibility issue with the OLED.
Can you try to use one old firmware and in particular https://github.com/cecio/USBvalve/releases/download/v0.17.0/USBvalve-0.17.0-64.uf2

This version was using a different OLED library, give it a try and let me know.

cecio, 2024-07-17:
ok, I probably found the reason: your display use the `SH1106` chip. The library currently used by USBvalve is the `Adafruit SSD1306` and it seems it does not support the other chip:

https://github.com/adafruit/Adafruit_SSD1306/issues/14

Try to use the old firmware as suggested in my previous message, it may work. If not, you probably need to switch the library. I don't know if you are familiar with development or not.

I may consider to switch the library to something with wider support, but  I'd like to find something with a solid installed base.

markthwain1797, 2024-07-18:
The version you suggested (v0.17.0) seems to work perfectly fine for me.
I'd be really interested in testing if you try out different librarys that support types of displays.

cecio, 2024-07-18:
OK, great! I'm happy it worked.

I switched to this new library to improve compatibility, but it seems in some cases the old one was better.

I'll try to have a look if I can keep compatibility for both.

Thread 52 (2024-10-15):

UF2 file not booting

Onexkings, 2024-10-15:
Hi everyone,

I’m still new to this USB valve project, and i have encounter an issue. I’ve flashed a UF2 blink test file to my Raspberry Pi Pico to make sure it was working, and it works fine. However, when I try the USBvalve-0.19.0-64.uf2 file to the Pico, nothing happens—the OLED display remains off, and I’m not seeing any output.

Here’s what I’ve checked:

The Pico is in bootloader mode when flashing the UF2 file.
I resolder pin GND2 and VCC2

Since im new to this, i dont know if i need a libary or another aplication to work with this Pico
If anyone has experienced similar issues or has suggestions on how to troubleshoot this further, I would really appreciate your guidance!

Thank you!

cecio, 2024-10-15:
Hey.

No, you don't need anything else to use it.
I would check if it's a display issue: once you flashed the USBvalve firmware, could you try to attach it to a PC? Do you see any attached device if you do so? For example in Windows you should see a new USB device attached, in Linux you may have to mount it manually, but you should see a new USB device as well.

In this way we can understand if the problem is the display compatibility/connection.
Let me know,
Thanks,

Onexkings, 2024-10-16:
Hello,

Thank you for replying, I've bought a new pico as well an oled to makesure that its not the pico problem aswell as an oled issue. Before i asemble it to the PCB, I've tested it out using a breadboard and it works! im worried that if i assemble it to a PCB, it won't work again, but im not sure and haven't tested it yet.

But, I really appreciate your guidance and support as I navigated this project as a beginner. Thank you once again for your help!

Thank you!

Onexkings, 2024-10-16:
Hello,

I've solderd everything to the PCB and same issue the oled wont display, so could it be the PCB problem here?

cecio, 2024-10-16:
It could be different things, but first of all we need to understand if the USBvalve firmware is working (except for the OLED). So, after you upload the firmware, do you see a new USB device on your system?
If so, the problem is in the OLED, and it could be:

- incompatible OLED. The OLED should be based on `SSD1306`. Other may work, but not always.
- OLED connection not correct. Check again if you soldered the right PINs

In case of incompatible display, you can have a look to issue #49 and may be try the firmware version 0.17.0

Let me know how it goes.

Onexkings, 2024-10-26:
Hi,

I apologize for my delayed response, I nearly forgot about my question. I also appreciate your patience as I provide an update regarding my issue.

I’d like to answer your question now. Yes, I see a new USB device on my system.

I found the issue after soldering everything to the PCB. The new Pico and OLED worked fine on the breadboard, but the OLED didn’t turn on when soldered to the PCB. I connected a jumper wire from the Pico pin directly to the OLED pins, and that fixed it. I had the same problem with the USB not providing voltage, so I also jumped a cable from the Pico to the USB socket, and it worked!

If I'm not mistaken, the issue seems to be with the PCB wiring diagram. Or it could be my pcb manufacture problem?? but im not sure. I did put a blob on the OLED power pads, but there was still no result.

Thank you for your assistance!

cecio, 2024-10-26:
no worries, thanks for the additional details.

The PCB wiring diagram is fine, I built hundreds of them with the same diagram. It could be a problem in the manufacturing  of your PCB, but it's unlikely.

Try to have a look at this [video](https://www.youtube.com/watch?v=7ymk8hD7-Hc). At minute 8:09, it explains how to solder the power pads:
- be sure that you put solders on only two of them
- be sure that they are correctly soldered (sometimes these little pads seems soldered, but if you look carefully with a magnifier, they aren't)
- be sure to solder the right two (which, in most cases, are the same two shown in the video. You can understand which are the correct two by checking the README)

Let me know if this helps.

cecio, 2024-11-19:
stale

Closed 2024-11-19.

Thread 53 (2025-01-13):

Feature request: Counter for input strokes

dxniro, 2025-01-13:
Hi!

First of all: Thank you for the cool project you set up! :)

What do you think about having a counter on the display for HID devices, which shows how many inputs were made (for example keystrokes). This would be helpful especially if you want to have an unknown usb device connected for a longer period of time to check whether it is doing something anomalous after a specific time or not.

The counter could probably be placed next to the "HID Device sending data... (counter)" and could be refreshed every one minute (or every time, an new input comes in). I was thinking of two variations:

- Refresh the display & keep the counter in the same line
- Append a new line after an specific period of time with the refreshed counter

What do you think about this? Would this maybe be a useful feature?

Best regards,
Daniel

cecio, 2025-01-13:
Hey Daniel! :-)

Thanks a lot for your kind words and for participating actively to the project with your request!

Your proposal is interesting, but let me try to better understand the need.

In my mind I have two main use cases when I think to the USB devices detection:

- detached usage (so, no PC available, just the *USBvalve* device): in this case I consider to attach the unknown device to *USBvalve* and let it attached to it for the time I need (one second or one hour). In this case if I see any kind of activity as HID device (no matter if 1 or 1000 char), I would consider the device suspicious and I would not attach it to anything important
- attached usage (PC available): in this second case I can attach to the serial device from the PC and monitor the complete activity of the HID device also displaying any output coming from it (like [this](https://asciinema.org/a/NWfC9Mvzzpj3eZfsC7s5Dz1sJ)). So even in this case, knowing the number of keystrokes on the panel, is not adding a critical information

But that said, I'd like to know why you consider this information useful and in which case it would be worth to have it available on the OLED screen. May be there is something I didn't considered. :-)

Thanks a lot for your time and for your interest in the project!

dxniro, 2025-01-15:
Hi cecio,

thank you for your feedback!

The case is maybe really rare, but there would be a small change, that you could plugin an device, which you expect to be an HID device, and that it will do nothing suspicious, until you started to use it. Let's say you have an untrustworthy keyboard, which acts like a rubber ducky, but with the difference, that it is waiting, until you started to use the keyboard or to type the first few key strokes.

If USBvalve would show me, how much inputs were already made I could type in something randomly and then let it plugged in and not touch it for let's say an hour. When the counter increases, I know that this is really suspicious. With the current state, it would always show me only "sending data".

Also if you plug in a mouse, which is really sensitive, you could easily trigger the "HID device sending data..." by just plugging in the mouse. With the counter I could keep track of it, whether there are more inputs coming in or if it was just me moving the mouse by accident.

Hopefully, this explains it better to you, what I thought about it, when I wrote this request :)

Have a nice day!

cecio, 2025-01-15:
Thanks for your additional thoughts!

Ok, I got your points. I'll give it a try to see how it may work.

Thanks for your input so far.

Have a nice day you too!

cecio, 2025-01-28:
I tried different solution for this, but this is going to clutter the tiny OLED.

So, I'm thinking to make this optional and printable with a long press of the BOOTSEL button. So at the end it will be:
- short press (under 2 seconds): RESET (as it is right now)
- long press: print HID events number

dxniro, 2025-01-30:
That sounds good to me! :)

cecio, 2025-02-02:
Implemented in release `0.21.0` (d756e20eb4a4a87d770daf3bcb9ca3a2fa89ac30)

Closed 2025-02-02.

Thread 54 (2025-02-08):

No screen output despite successful flashing

FabianKnebel, 2025-02-08:
Hi,

First of all: great project, thank you!

I'm fairly new to DIY projects and think I need some help with my problem:
I can't get any output on the OLED screen.

It seems like the firmware is working correctly because:
I successfully uploaded the firmware and the custom drive appears.
Also it seems to run, because the LED on the Pico is on and turns off when I connect my keyboard to the USB host.
However, the screen stays black all the time.

What I’ve Tried:
- Tested the wiring and screen (the x64 one) with a separate script, where the screen displayed the test correctly. So this shouldn't be the problem.
- Tried both 128x64 and 128x32 OLED screens with their respective firmwares. The issue occures on both screen sizes.
- Tested older firmwares (down to 0.17.0), but the issue persists.

I’m attaching a photo of my wiring for reference.
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

Any idea what I might be doing wrong?
Thanks in advance for your help!

cecio, 2025-02-08:
Hey!
Thanks for your interest into the project!

From what you say the issue seems to be a compatibility with your OLED. Could you check if your screen is based on `SSD1306` IC? If not, this could be the reason.

FabianKnebel, 2025-02-09:
Thanks for the quick reply.

This is the [display](https://www.az-delivery.de/products/0-96zolldisplay?variant=26462805705) I use.
At least it has `SSD1306` in the product name.. Also I used the SSD1306 library in my test to check the wiring. And this worked.

cecio, 2025-02-09:
OK, try to play a bit with this value (line 83):

```
#define I2C_ADDRESS 0x3C
```

Looking at the link you sent me, it looks it uses something like `0x78` or `0x7a`. Then you need to recompile. I suggest you to use the dockerfile included for that, it will simplify a lot the process. Or, if you struggle in doing that let me know, I can provide a couple of custom firmware.

FabianKnebel, 2025-02-09:
Thanks for taking a closer look.

I briefly tried to recompile it, but failed the process. And it's not something I can dig deeper into now.

It would be great if you could provide custom firmware!

cecio, 2025-02-09:
I'm attaching two versions for the 32 lines. Let me know if one of them work.

[fw.zip](https://github.com/user-attachments/files/18724130/fw.zip)

cecio, 2025-02-09:
I realize now that you showed the link for the 64 lines version, so it's probably better to test this one :-)
Here the 64 line versions:

[fw_64.zip](https://github.com/user-attachments/files/18724170/fw_64.zip)

FabianKnebel, 2025-02-09:
Thank you for your effort, but I got the same behavior. The on board LED acts like expected, but still no output on the OLEDs for me.

I tried both versions of the 32 line and 64 line displays - even with another Pico and display.
Also I can proof, that in principle my wiring and the screen itself work:
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

Any other ideas? Am I maybe using wrong boards ([these](https://www.amazon.de/dp/B09TSWP4RV))?

cecio, 2025-02-09:
I see.

Which code are you using for the "Hello World" sample? One of the standard examples? Can you identify the I2C address used to initialize the screen?

cecio, 2025-02-09:
Try this one (64 lines), may be we are lucky.

[fw_3d_64.zip](https://github.com/user-attachments/files/18724597/fw_3d_64.zip)

FabianKnebel, 2025-02-09:
This sadly also didn't help.

This is my testing code:
```
from machine import Pin, I2C
import ssd1306

# Initialize I2C
i2c = I2C(1, scl=Pin(7), sda=Pin(6))

# Create the display object (width=128, height=64)
oled = ssd1306.SSD1306_I2C(128, 64, i2c)

# Clear the screen
oled.fill(0)
oled.show()

# Display text
oled.text("Hello, World!", 0, 0)
oled.show()
```

Is this correct to identify the I2C address?
```
from machine import Pin, I2C

i2c = I2C(1, scl=Pin(7), sda=Pin(6))
devices = i2c.scan()

if devices:
    print("I2C devices found:", [hex(device) for device in devices])
else:
    print("No I2C devices found.")
```
Output:
`I2C devices found: ['0x3c']`

cecio, 2025-02-09:
Looking closer at the picture you posted, it looks you are using the wrong PINs for SDA and SCL.
If I count the PIN you are using 9 and 10, but you should use 6 and 7.
Try to double check this

FabianKnebel, 2025-02-09:
OMG, you are absolutely right!
I thought it was GP6 and GP7, that's why I used PIN 9 and 10..
Now it works with the default firmware.

Thank you anyway for the support!

cecio, 2025-02-09:
Great! Happy it is solved now!

Closed 2025-02-09.

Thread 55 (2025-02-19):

Pico 2 crashes

deriggsm, 2025-02-19:
HID device and microboard issue

deriggsm, 2025-02-25:
Pico 2w, causes disconnected causes a crashes works properly when connected. Could be Wifi or blue tooth

https://github.com/user-attachments/assets/cf6cab32-0a72-407b-a57a-715c72d4eb21

cecio, 2025-02-25:
mmmhhh, I see.
The output you see (the sequence of  `(0 0 0)`) should not happen, because in the code every print of this string should be preceded by a `MOUSE:`  string. That means that something broken the code flow.

Did you recompiled the code before uploading it to the `Pico 2W`? Because the provided firmware is compiled for the standard `Pico 2` and the two formats are  different.
So my best guess right now is that, if you uploaded the firmware provided in the repository, it is not compatible. You should recompile it for the `2W`.

Let me know if this is the case.
Thanks

Closed 2025-03-22.

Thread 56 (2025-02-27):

Nothing happens when plugging USB drive to USBvalve

Mikitwin, 2025-02-27:
I built my USBvalve with the PCB thanks to Tzirf's tutorial. However, when I plug a USB drive, nothing changes on the USBvalve screen. I only get "USBvalve - 0.19.1" and "Selftest: OK". I would expect a "Mass storage" message when looking at Tzirf's second tutorial. There is also no light turning on on the inserted USB drive. I checked a few PCB connections with a multimeter already but didn't find anything obvious for now. The firmware seems to works since I can modify the text file if I plug the USBvalve to my PC and I get a warning on screen. I'm suspecting a problem with the USB connector, but I'm not sure what to look for. For reference, I'm using the version 1.2 USB A PCB. Any help would be much appreciated!

Mikitwin, 2025-03-01:
Hi,

I tested a mouse and a keyboard, but I had the same issue. I checked the traces and soldering more carefully with a multimeter to realize that I was a bit light on solder for the USB connector and the signals were not going from the PCB to the USB connector. Rookie mistake... I added more solder and flux but same issue. Then I just tried to press the reset button and it worked! My USB drive was not recognized automatically when I inserted it into a powered USBvalve, but it was if I pressed the reset button. I only realized later that it was a boot drive, so I don't know how it interacts with the USBvalve. Using another regular USB drive fixed the problem. Thank you for your help and for creating this amazing project!

cecio, 2025-03-01:
Thanks to you for your feedback!

Closed 2025-03-01.

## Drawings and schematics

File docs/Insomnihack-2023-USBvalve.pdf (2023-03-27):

# USBValve

expose USB activity on the fly!

# Hello!

I am Cesare Pizzi, I’m doing security things at Sorint.lab
I am here because I love hacking (and thanks to the organizers!) You can find me at “@red5heep” and “https://github.com/cecio”

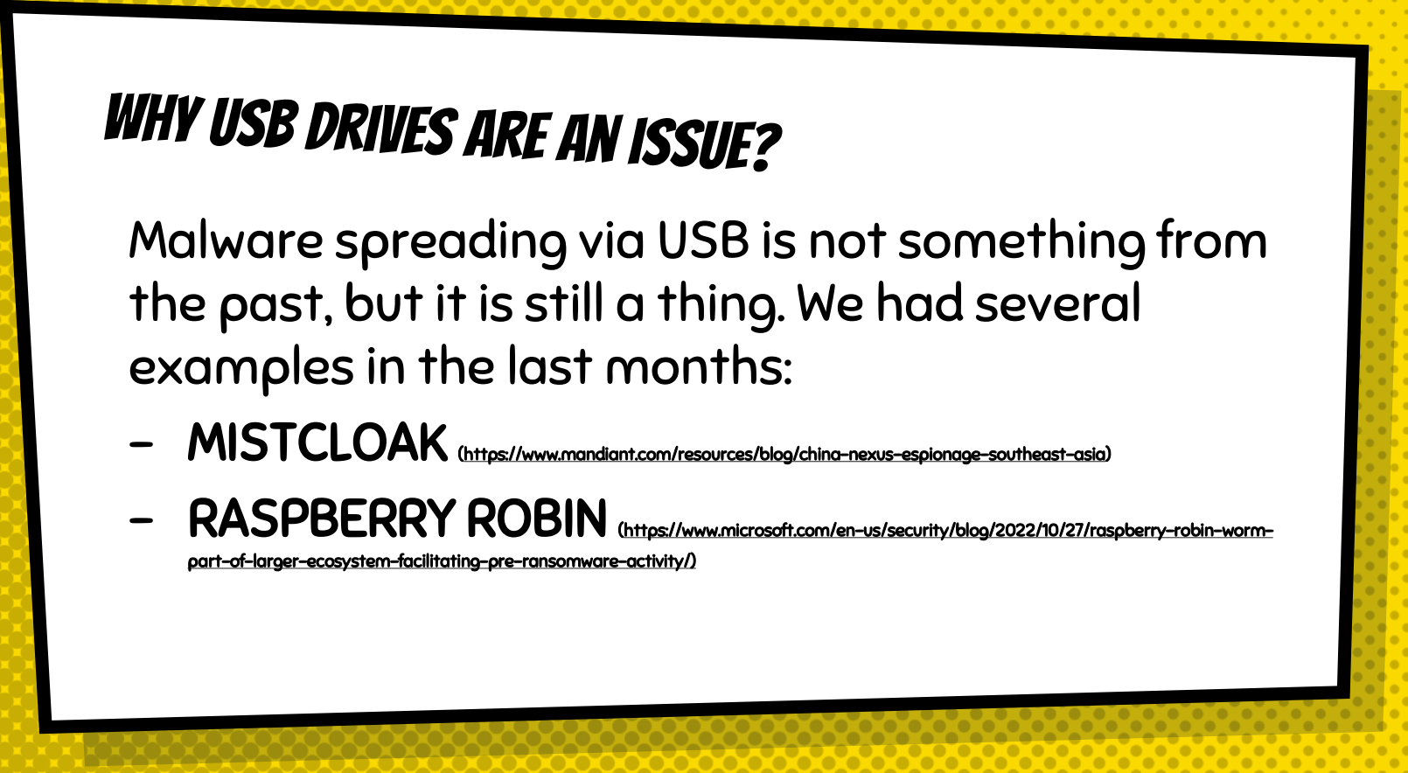
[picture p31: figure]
examples in the last months:; part-of-larger-ecosystem-facilitating-pre-ransomware-activity/)

Malware spreading via USB is not something from the past, but it is still a thing. We had several

- MISTCLOAK (https://www.mandiant.com/resources/blog/china-nexus-espionage-southeast-asia)
- RASPBERRY ROBIN (https://www.microsoft.com/en-us/security/blog/2022/10/27/raspberry-robin-worm-

- NJRAT (https://infosecwriteups.com/njrat-malware-analysis-8e90dce07a9e)

- Try2cry (https://www.bleepingcomputer.com/news/security/try2cry-ransomware-tries-to-worm-its-way-to-other-windows-

- PlugX (https://unit42.paloaltonetworks.com/plugx-variants-in-usbs/)

But why using USB to spread in 2023?
× Implementation is pretty easy
× USB drives are easily exchanged without
precautions
× USB allows “spillover” (different networks or
even air gapped systems)

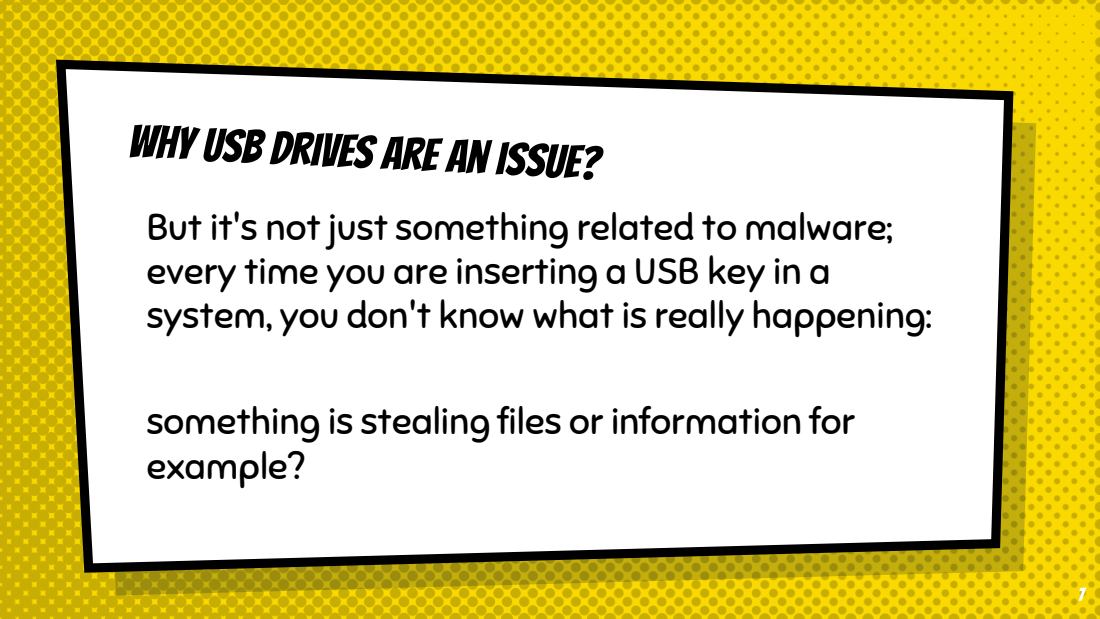
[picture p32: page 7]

But it's not just something related to malware;
every time you are inserting a USB key in a
system, you don't know what is really happening:

something is stealing files or information for
example?

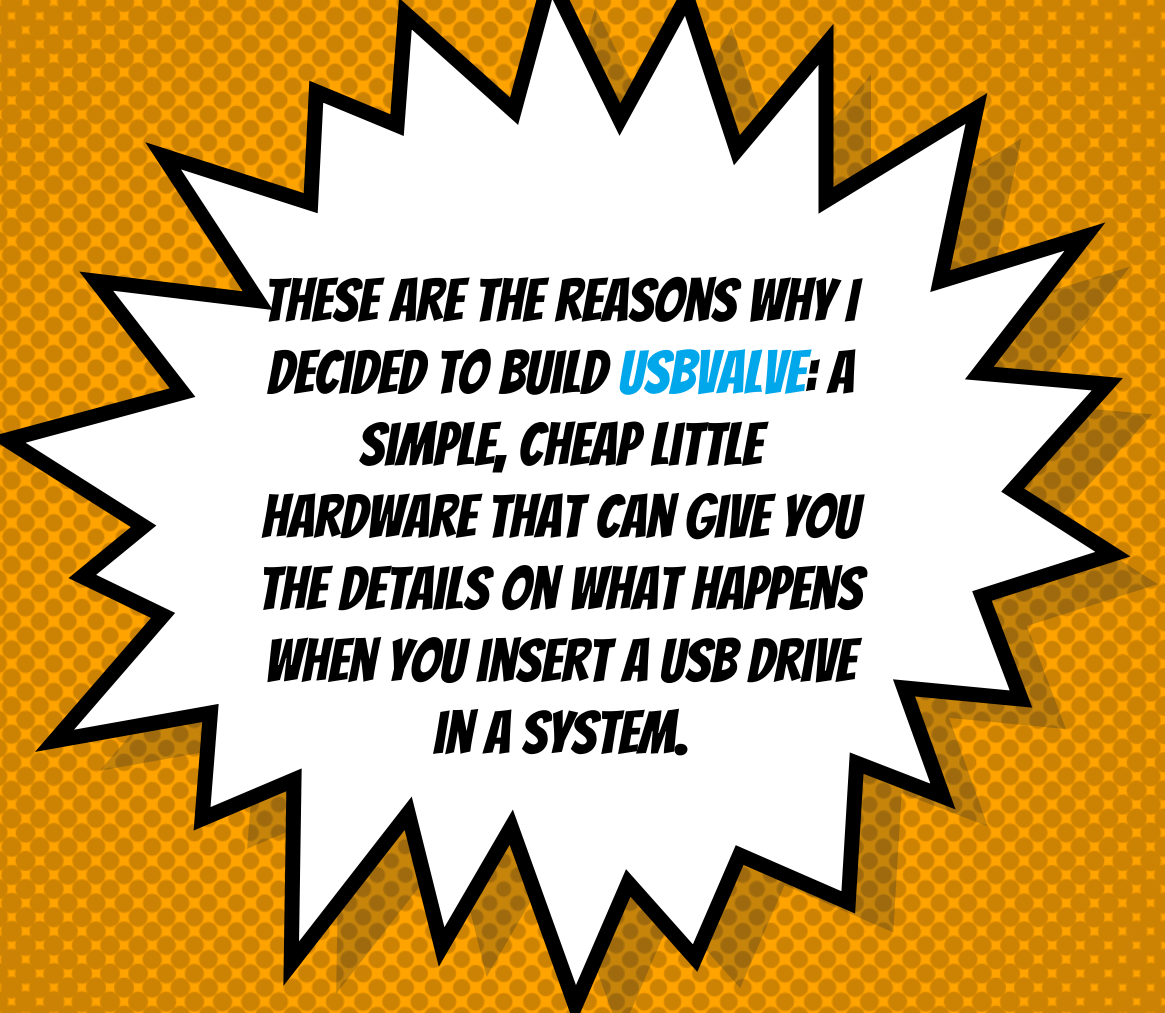
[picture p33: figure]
These are the reasons why I decided to build USBvalve: a simple, cheap little hardware that can give you the details on what happens when you insert a USB drive in a system.

I decided to build this on well-known, cheap, off-
the-shelf hardware, so I opted for:
× Raspberry Pi Pico (6$)
× OLED SSD1306 screen (8$) to give immediate
output

To keep thing simple I tried to avoid to use a real
SD card and I emulated everything I needed.
In this way you just need a couple of components
to have the fully working project.

The very same code should run on any “rp2040”
based platform supporting “TinyUSB”

I decided to create also a super simple custom
PCB, but you can build your own also without

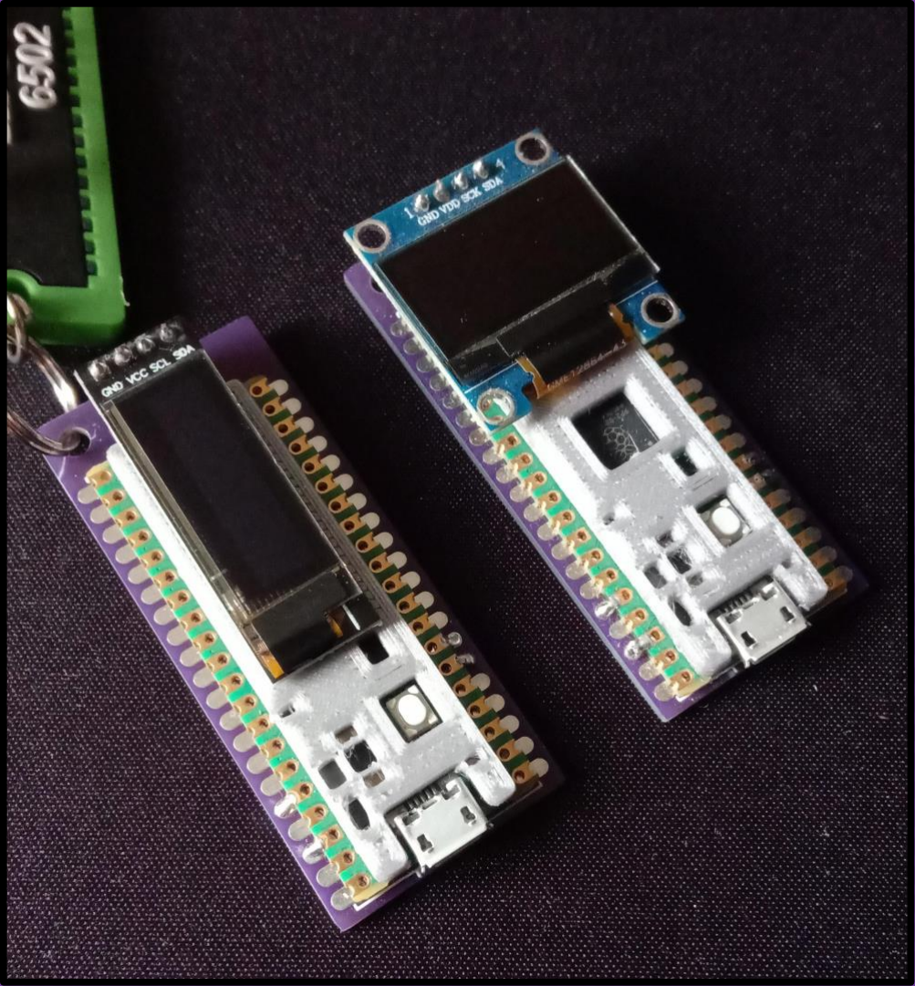
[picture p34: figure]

### The final result

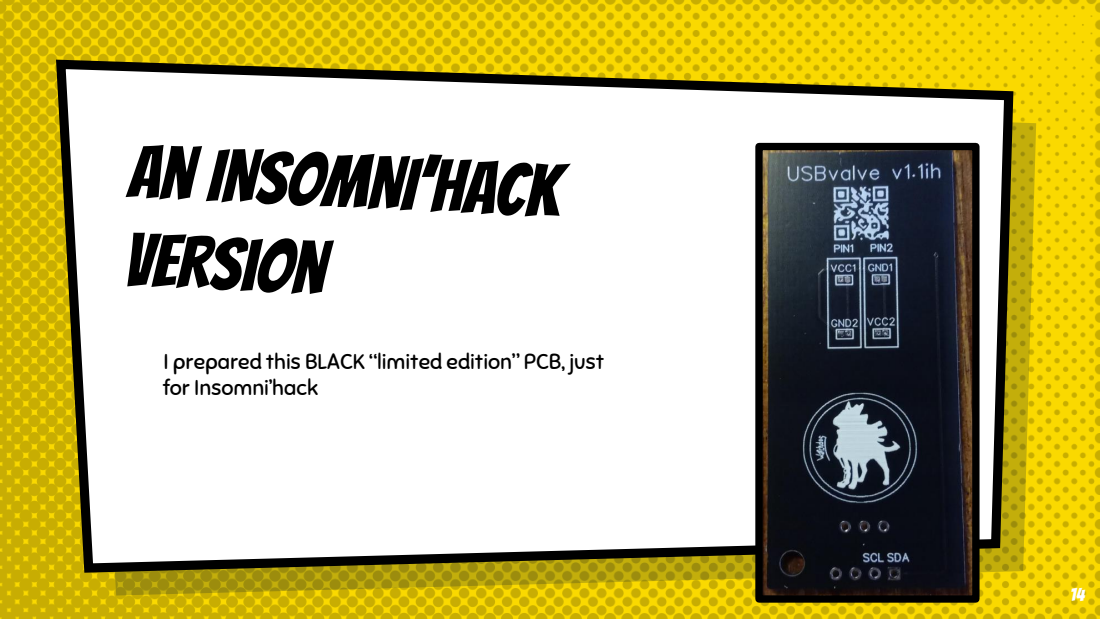
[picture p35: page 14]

I prepared this BLACK “limited edition” PCB, just
for Insomni’hack

Based on “TinyUSB” library the system build a
complete fake Filesystem directly in the RAM of
the “Pico” and monitor for what is going on.

The File System has been crafted to expose more
space than what is actually available in the
memory of the board: we are not storing files, just
checking accesses!

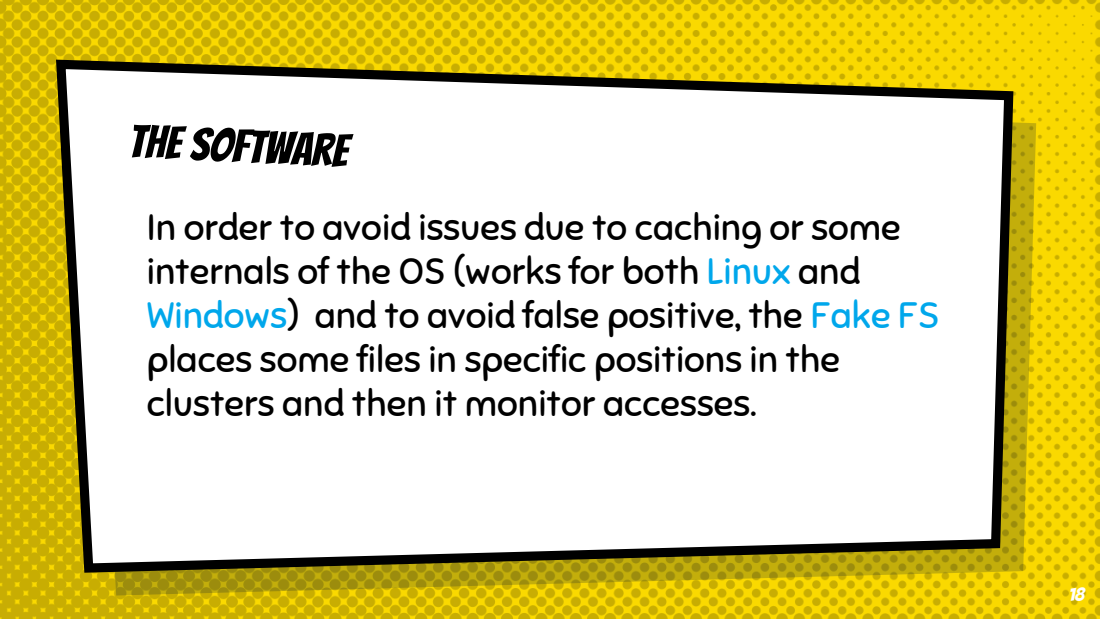
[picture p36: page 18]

In order to avoid issues due to caching or some
internals of the OS (works for both Linux and
Windows) and to avoid false positive, the Fake FS
places some files in specific positions in the
clusters and then it monitor accesses.

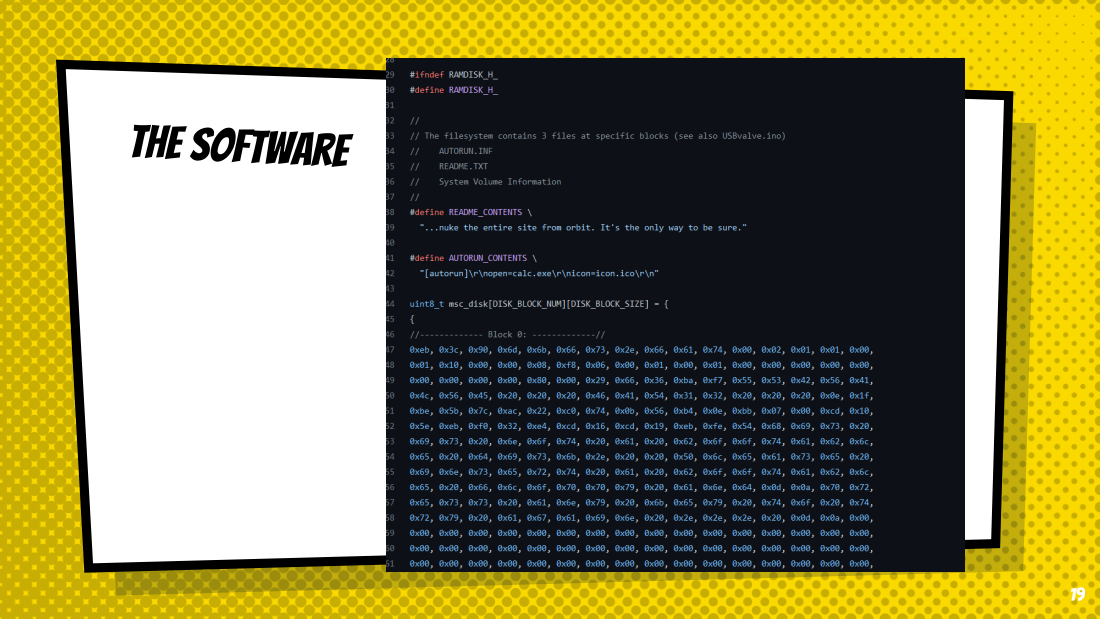
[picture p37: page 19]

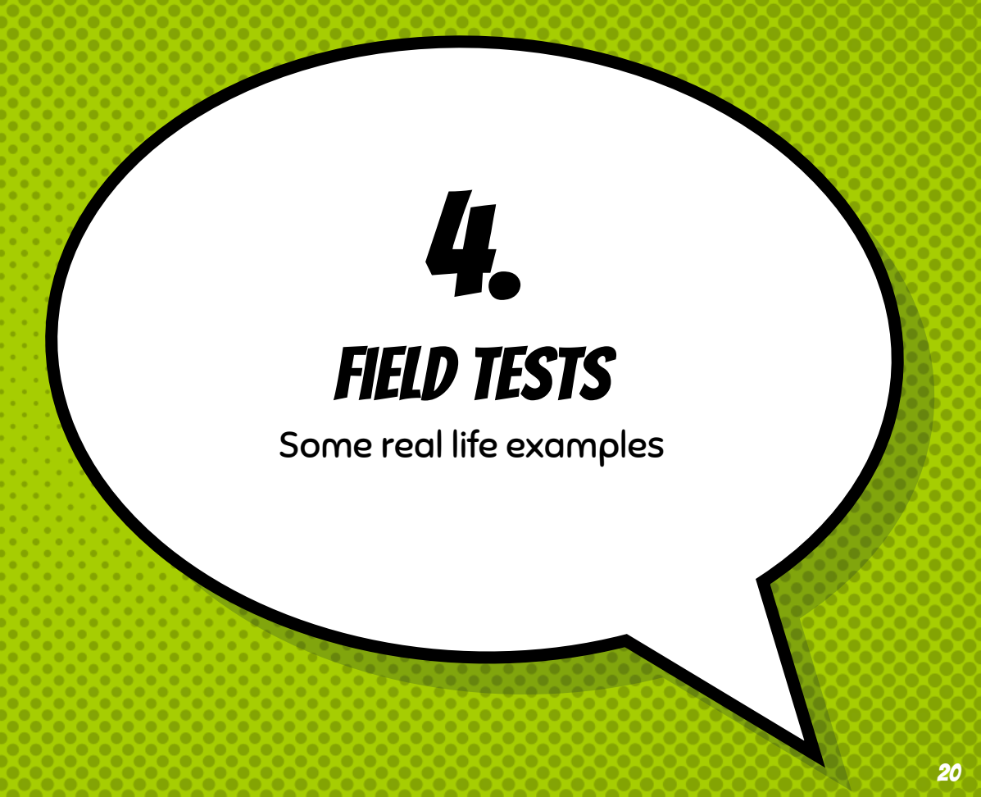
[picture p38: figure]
Field tests; Some real life examples

We’ll go through 4 malwares which will use 4
different techniques to trigger the execution,
some of them pretty naive, some more
sophisticated.
Obviously all the USB activities will be catched
and exposed by USBvalve.

It looks like that malware authors using USB
spread techniques, prefer to use .NET
executables.
May be because we are examining some simple
malware samples?

This can be true for njrat and try2cry, but for
Raspberry Robin and PlugX it’s another story: we
are actually facing something more complex and
structured.

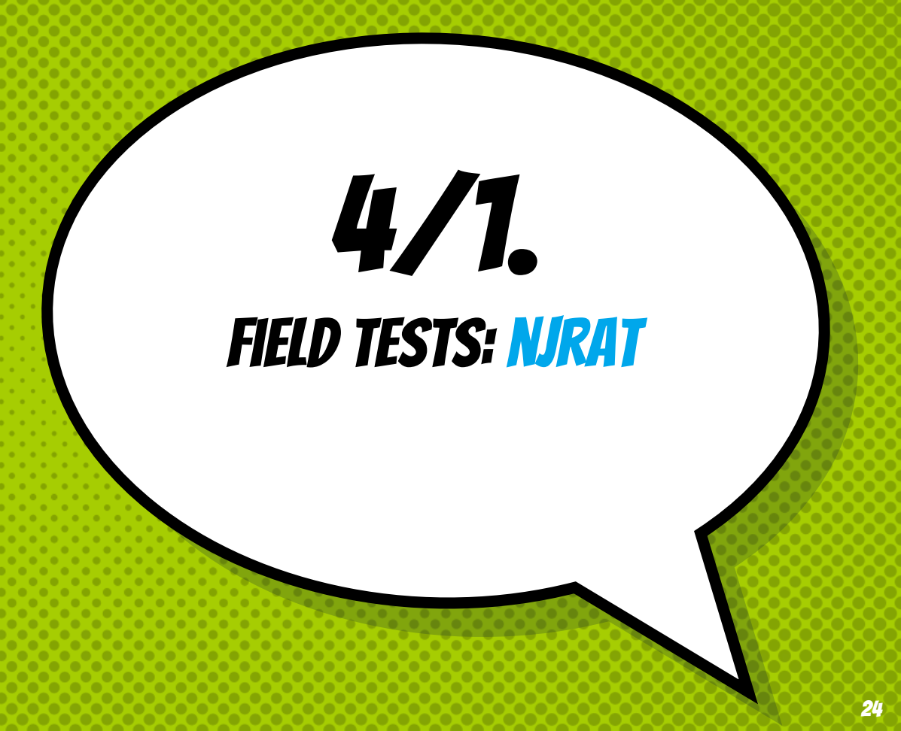
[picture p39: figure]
Field tests: njrat

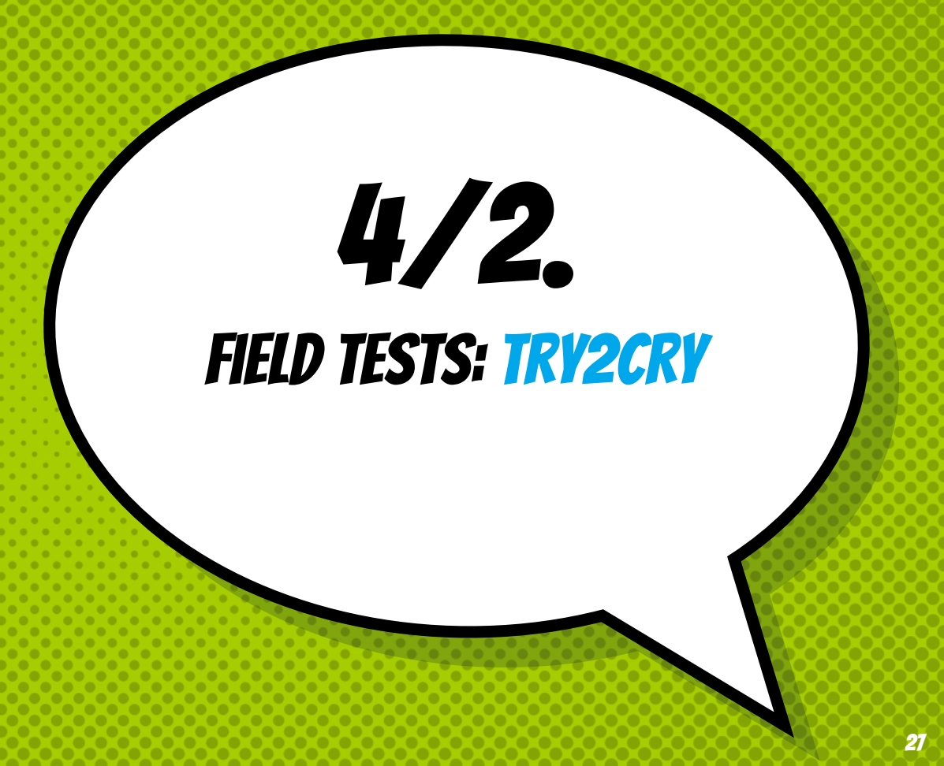
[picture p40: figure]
Field tests: try2cry

…with some "fancy"
file names (in arabic),
hoping that the user
will click on them

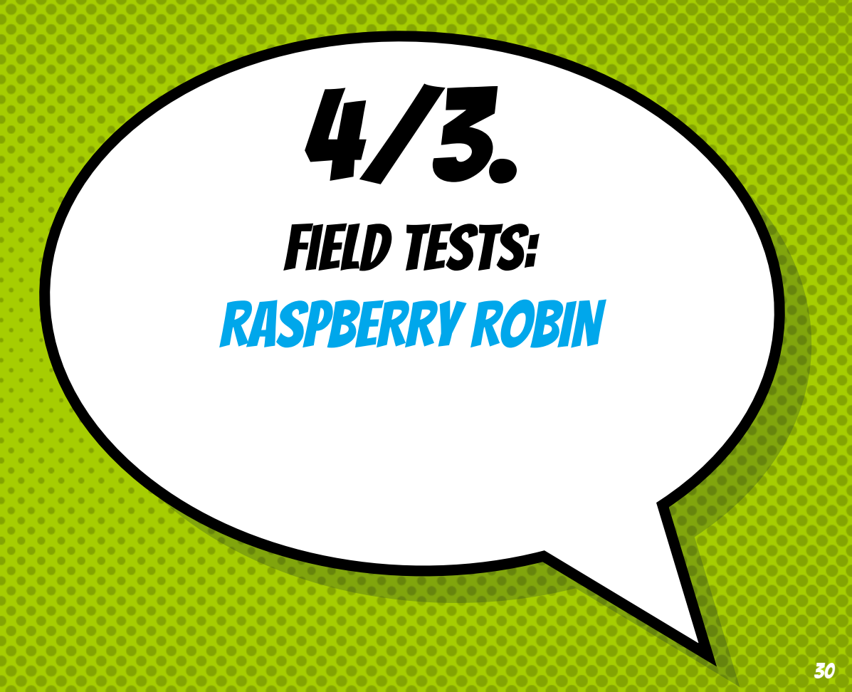
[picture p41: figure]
Field tests: RASPBERRY ROBIN

This malware is pretty complex and composed of
several parts.
MS and Red Canary did awesome analysis on it.

× https://redcanary.com/blog/raspberry-robin/
× https://www.microsoft.com/en-
us/security/blog/2022/10/27/raspberry-robin-
worm-part-of-larger-ecosystem-facilitating-
pre-ransomware-activity/ (https://www.microsoft.com/en-us/security/blog/2022/10/27/raspberry-robin-worm-part-of-larger-ecosystem-facilitating-pre-ransomware-activity/)

From the MS
site
mentioned
before

If you really want an insight about the complexity
behind Raspberry Robin and Roshtyak, have a
look to this awesome report from AVAST:
× https://decoded.avast.io/janvojtesek/raspberry-robins-
roshtyak-a-little-lesson-in-trickery/?s=09 (https://decoded.avast.io/janvojtesek/raspberry-robins-roshtyak-a-little-lesson-in-trickery/?s=09)
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

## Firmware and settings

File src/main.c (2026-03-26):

/*
 * USBvalve - Pure Pico SDK Implementation
 *
 * USB security tool: acts as USB Mass Storage Device (Core 0) while
 * simultaneously running USB Host via PIO USB (Core 1) to detect
 * BadUSB/HID attacks.
 *
 * Copyright (c) Cesare Pizzi
 * MIT License
 */

#include <stdio.h>
#include <string.h>
#include "pico/stdlib.h"
#include "pico/multicore.h"
#include "hardware/gpio.h"
#include "hardware/watchdog.h"
#include "hardware/clocks.h"
#include "tusb.h"
#include "usb_config.h"
#include "usb_device.h"
#include "usb_host.h"
#include "display.h"
#include "serial_output.h"

#ifdef USE_BOOTSEL
#include "pico/bootrom.h"
#include "hardware/structs/ioqspi.h"
#include "hardware/structs/sio.h"
#endif

//--------------------------------------------------------------------
// Shared state (cross-core, volatile. ARM word writes are atomic)
//--------------------------------------------------------------------
volatile bool flag_readme = false;
volatile bool flag_autorun = false;
volatile bool flag_written = false;
volatile bool flag_deleted = false;
volatile bool flag_written_reported = false;
volatile bool flag_deleted_reported = false;
volatile bool flag_hid_sent = false;
volatile bool flag_hid_reported = false;
volatile bool flag_hid_mounted = false;
volatile bool flag_msc_mounted = false;
volatile bool flag_cdc_mounted = false;
volatile uint32_t hid_event_num = 0;

//--------------------------------------------------------------------
// Software reset via watchdog
//--------------------------------------------------------------------
static void swreset(void) {
    watchdog_enable(1500, 1);
    while (1) {
        tight_loop_contents();
    }
}

#ifdef USE_BOOTSEL
//--------------------------------------------------------------------
// BOOTSEL button check (multi-core safe)
//
// WARNING: Reading BOOTSEL temporarily disconnects flash (QSPI CS
// override), which crashes any core executing from flash. This
// disrupts PIO USB on Core 1 and causes unreliable Low Speed device
// detection. Only enable this on boards without an external button.
//
// Core 1 must call multicore_lockout_victim_init() at startup.
//--------------------------------------------------------------------
static bool __no_inline_not_in_flash_func(bootsel_pressed_raw)(void) {
    const uint CS_PIN_INDEX = 1;

    hw_write_masked(&ioqspi_hw->io[CS_PIN_INDEX].ctrl,
                    GPIO_OVERRIDE_LOW << IO_QSPI_GPIO_QSPI_SS_CTRL_OEOVER_LSB,
                    IO_QSPI_GPIO_QSPI_SS_CTRL_OEOVER_BITS);

    for (volatile int i = 0; i < 1000; i++);

    bool pressed = !(sio_hw->gpio_hi_in & (1u << CS_PIN_INDEX));

    hw_write_masked(&ioqspi_hw->io[CS_PIN_INDEX].ctrl,
                    GPIO_OVERRIDE_NORMAL << IO_QSPI_GPIO_QSPI_SS_CTRL_OEOVER_LSB,
                    IO_QSPI_GPIO_QSPI_SS_CTRL_OEOVER_BITS);

    return pressed;
}

static bool bootsel_pressed(void) {
    multicore_lockout_start_blocking();
    uint32_t flags = save_and_disable_interrupts();
    bool pressed = bootsel_pressed_raw();
    restore_interrupts(flags);
    multicore_lockout_end_blocking();
    return pressed;
}
#endif // USE_BOOTSEL

//--------------------------------------------------------------------
// Main (Core 0)
//--------------------------------------------------------------------
int main(void) {
    // Sysclock must be a multiple of 12MHz for PIO USB.
#if defined(PICO_RP2350)
    set_sys_clock_khz(144000, true);
#else
    set_sys_clock_khz(240000, true);
#endif
    sleep_ms(10);

    // Launch Core 1 for USB host BEFORE device init.
    // Core 1 handles PIO USB host. Must start first so PIO IRQs
    // are registered on Core 1.
    multicore_reset_core1();
    multicore_launch_core1(core1_entry);

    // Init device stack on native USB (rhport 0)
    tud_init(0);

    // Run ramdisk self-test
    bool selftest_ok = usb_device_selftest();

    // Initialize display
    display_init();
    cls();

    if (selftest_ok) {
        printout("\n[+] Selftest: OK");
    } else {
        printout("\n[!] Selftest: KO");
        printout("\n[!] Stopping...");
        while (1) {
            sleep_ms(1000);
        }
    }

#ifndef PIWATCH
    // Set up LED pin (PIWATCH uses GPIO 25 for backlight)
    gpio_init(LED_PIN);
    gpio_set_dir(LED_PIN, GPIO_OUT);
    gpio_put(LED_PIN, 1); // LED on = OK

    // Set up external reset button (active-low with pull-up)
    gpio_init(BUTTON_PIN);
    gpio_set_dir(BUTTON_PIN, GPIO_IN);
    gpio_pull_up(BUTTON_PIN);
#endif

    // Core 0 main loop
    while (true) {
        // Process TinyUSB device tasks (required for CDC serial + MSC)
        tud_task();

        // Flush CDC writes from Core 1 callbacks
        tud_cdc_write_flush();

        // Check flags and report events
        if (flag_readme) {
            printout("\n[!] README (R)");
            flag_readme = false;
#ifndef PIWATCH
            gpio_put(LED_PIN, 0);
#endif
        }

        if (flag_autorun) {
            printout("\n[+] AUTORUN (R)");
            flag_autorun = false;
        }

        if (flag_deleted && !flag_deleted_reported) {
            printout("\n[!] DELETING");
            flag_deleted = false;
            flag_deleted_reported = true;
#ifndef PIWATCH
            gpio_put(LED_PIN, 0);
#endif
        }

        if (flag_written && !flag_written_reported) {
            printout("\n[!] WRITING");
            flag_written = false;
            flag_written_reported = true;
#ifndef PIWATCH
            gpio_put(LED_PIN, 0);
#endif
        }

        if (flag_hid_mounted) {
            printout("\n[!!] HID Device");
            flag_hid_mounted = false;
#ifndef PIWATCH
            gpio_put(LED_PIN, 0);
#endif
        }

        if (flag_msc_mounted) {
            printout("\n[++] Mass Device");
            flag_msc_mounted = false;
        }

        if (flag_cdc_mounted) {
            printout("\n[++] CDC Device");
            flag_cdc_mounted = false;
        }

        if (flag_hid_sent && !flag_hid_reported) {
            printout("\n[!!] HID Sending data");
            flag_hid_sent = false;
            flag_hid_reported = true;
#ifndef PIWATCH
            gpio_put(LED_PIN, 0);
#endif
        }

#ifndef PIWATCH
        // External button on GPIO 0 (active-low, debounced)
        if (!gpio_get(BUTTON_PIN)) {
            sleep_ms(50); // debounce
            if (!gpio_get(BUTTON_PIN)) {
                uint32_t press_start = to_ms_since_boot(get_absolute_time());
                while (!gpio_get(BUTTON_PIN)) {
                    sleep_ms(10);
                }
                uint32_t press_duration = to_ms_since_boot(get_absolute_time()) - press_start;

                if (press_duration > 2000) {
                    // Long press: show HID event count
                    char outstr[32];
                    snprintf(outstr, sizeof(outstr), "\n[+] HID Evt# %u", (unsigned)hid_event_num);
                    printout(outstr);
                } else {
                    // Short press: reset
                    printout("\n[+] RESETTING");
                    swreset();
                }
            }
        }
#endif // !PIWATCH

        // CDC serial commands
        // 'r'/'R' = reset, 'h'/'H' = HID event count
        if (tud_cdc_available()) {
            char buf[64];
            uint32_t count = tud_cdc_read(buf, sizeof(buf));
            for (uint32_t i = 0; i < count; i++) {
                switch (buf[i]) {
                    case 'r': case 'R':
                        printout("\n[+] RESETTING");
                        swreset();
                        break;
                    case 'h': case 'H': {
                        char outstr[32];
                        snprintf(outstr, sizeof(outstr), "\n[+] HID Evt# %u", (unsigned)hid_event_num);
                        printout(outstr);
                        break;
                    }
                    default:
                        break;
                }
            }
        }

#ifdef USE_BOOTSEL
        // BOOTSEL polling (disabled by default, disrupts Low Speed USB).
        // Only enable via -DUSE_BOOTSEL for boards without external button.
        static uint32_t last_bootsel_check = 0;
        uint32_t now = to_ms_since_boot(get_absolute_time());
        if (now - last_bootsel_check > 1500) {
            last_bootsel_check = now;
            if (bootsel_pressed()) {
                uint32_t press_start = to_ms_since_boot(get_absolute_time());
                while (bootsel_pressed()) {
                    sleep_ms(10);
                }
                uint32_t press_duration = to_ms_since_boot(get_absolute_time()) - press_start;

                if (press_duration > 2000) {
                    char outstr[32];
                    snprintf(outstr, sizeof(outstr), "\n[+] HID Evt# %u", (unsigned)hid_event_num);
                    printout(outstr);
                } else {
                    printout("\n[+] RESETTING");
                    swreset();
                }
            }
        }
#endif // USE_BOOTSEL
    }

    return 0;
}

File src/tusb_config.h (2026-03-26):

#ifndef TUSB_CONFIG_H
#define TUSB_CONFIG_H

#ifdef __cplusplus
extern "C" {
#endif

//--------------------------------------------------------------------
// Common Configuration
//--------------------------------------------------------------------
#define CFG_TUSB_OS           OPT_OS_PICO

#ifndef CFG_TUSB_MEM_SECTION
#define CFG_TUSB_MEM_SECTION
#endif

#ifndef CFG_TUSB_MEM_ALIGN
#define CFG_TUSB_MEM_ALIGN    __attribute__((aligned(4)))
#endif

//--------------------------------------------------------------------
// Device Configuration (rhport 0 = native USB)
//--------------------------------------------------------------------
#define CFG_TUD_ENABLED       1

#ifndef CFG_TUD_ENDPOINT0_SIZE
#define CFG_TUD_ENDPOINT0_SIZE  64
#endif

// Device classes
#define CFG_TUD_CDC           1
#define CFG_TUD_MSC           1
#define CFG_TUD_HID           0
#define CFG_TUD_MIDI          0
#define CFG_TUD_VENDOR        0

// CDC FIFO sizes
#define CFG_TUD_CDC_RX_BUFSIZE  256
#define CFG_TUD_CDC_TX_BUFSIZE  256

// MSC buffer size
#define CFG_TUD_MSC_EP_BUFSIZE  512

//--------------------------------------------------------------------
// Host Configuration (rhport 1 = PIO USB)
//--------------------------------------------------------------------
#define CFG_TUH_ENABLED       1
#define CFG_TUH_RPI_PIO_USB   1

// Host classes
#define CFG_TUH_HID           4
#define CFG_TUH_MSC           1
#define CFG_TUH_CDC           1
#define CFG_TUH_HUB           0

// Max devices
#define CFG_TUH_DEVICE_MAX    1
#define CFG_TUH_ENUMERATION_BUFSIZE 256

// HID buffer
#define CFG_TUH_HID_EPIN_BUFSIZE   64
#define CFG_TUH_HID_EPOUT_BUFSIZE  64

// CDC FIFO sizes for host
#define CFG_TUH_CDC_RX_BUFSIZE  64
#define CFG_TUH_CDC_TX_BUFSIZE  64

#ifdef __cplusplus
}
#endif

#endif // TUSB_CONFIG_H

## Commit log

2023-03-27 - modified FS consistency check to check FAT_DIRECTORY only (others sectors are not needed) - position of FS check chnaged - new hash inserted - modifications to compile with TinyUSB 2.0.1 and Board 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
2023-04-03 Gerber file renamed
2023-04-13 Add STL files (#2)
    * Create .gitkeep
    * STL files
    STL files for a box and a cover for the 128x32 screen
    * Delete .gitkeep
    [Box_USBvalve.stl, Cover_32_USBvalve.stl]
2023-04-13 Updated STL files (#3)
    * Updated STL files
    Updated STL files for the lid with more grip
    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
    [Box_USBvalve.stl, Cover_32_USBvalve.stl]
2023-04-22 renamed STL files
    [Box_USBvalve_1.1.stl, Cover_32_USBvalve_1.1.stl]
2023-05-01 minor update to PCB (ground connections)
2023-07-19 - HID serial read optimized - BOOTSEL now act as reset button - bump to release 0.12.0
2023-07-26 STL files for 1.2 PCB (#6)
    STL files for 1.2 PCB and 32 display cover.
    [Box_USBvalve_1.1.stl, Box_USBvalve_1.2.stl, Cover_32_USBvalve_1.1.stl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]
2023-09-08 - general clock speed lowered to 120Mhz and managed manually on core1 to achieve max compatibility for HID - hashing moved to XxHash for performance reason - bump to release 0.13.0 - upgrade board to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
2023-11-20 new logo and enclosure
    [USBvalve_sliding_cover.stl]
2024-04-14 Add USBpipe PCB (#33)
    * Add smart_usb_pipe Gerber file
    * Update PCB files and BOM
    * Update README.md
    * Fix README.md
    * Update README.md
    * Update README.md
    * Translate BOM into English and add ods formart
    * Replace PDF with PNG and SVG
    [BOM_USBpipe_Rev1.ods, BOM_USBpipe_Rev1.x.xlsx]
2024-04-19 added enclosure for 64 screen
    [SimpleEnclosurex64.stl, SimpleEnclosurex64_backplate.stl, SimpleEnclosurex64_spacer.stl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]
2024-08-04 Fix Document Mistake(#50) (#51)
    * Add Notification for R7&R8 of USBPipe
    * Document improvements
    [BOM_USBpipe_Rev1.ods, BOM_USBpipe_Rev1.x.xlsx]
2026-04-15 PCB 1.3 added
